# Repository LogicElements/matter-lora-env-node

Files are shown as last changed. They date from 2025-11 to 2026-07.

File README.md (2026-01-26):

# LocuSense – Low-Power CO₂ / T / RH / VOC Node (LoRaWAN / Matter over Thread)

LocuSense is a **battery-powered environmental sensing node** for CO₂, temperature, humidity and VOC index.
It is built around an ultra-low-power **STM32U0** MCU and can be equipped with **one of two mutually exclusive
communication modules**:

- **LoRaWAN (Wio-E5)** – long-range, ultra-low-power operation (few µA sleep current)
- **ESP32-C6 (Matter over Thread)** – fully integrated with Home Assistant as a sleepy end device (SED)

A 2.13" e-ink display shows current air quality and device status. It can be safely omitted in
long-life, headless deployments where every µA matters.

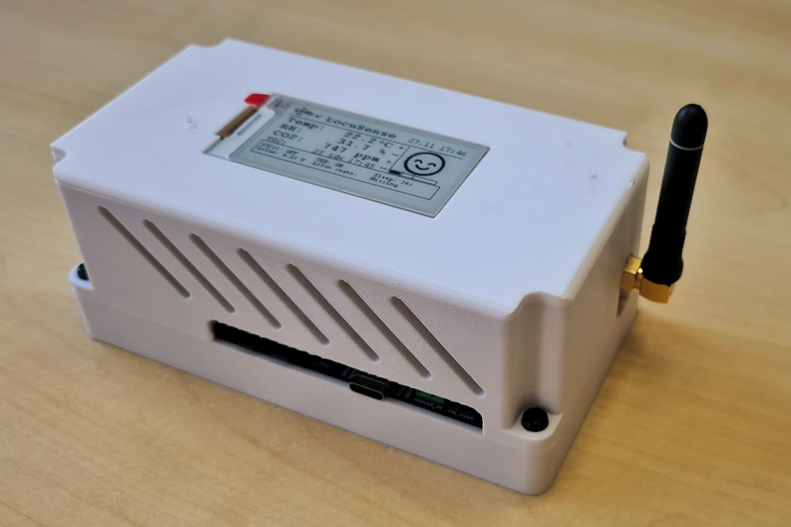
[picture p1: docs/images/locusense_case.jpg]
LocuSense node with e-ink display

---

## Features

### Sensing

- **CO₂** – Sensirion **SCD41**
- **Temperature & humidity** – Sensirion **SHT41**
- **VOC index** – Sensirion **SGP40** with official Gas Index Algorithm (VOC index)

### Power & batteries

- **STM32U0** ultra-low-power MCU
- Designed for **very low standby current** (few µA in LoRa STOP2 mode):
  - Switchable sensor / RF / e-ink power rails
  - Switchable pull-ups and resistor dividers
  - Deep sleep of external radios (Wio-E5 sleep, ESP32-C6 SED + light sleep)
- Dual battery support:
  - **LiSOCl₂ primary cell** for **multi-year, maintenance-free deployments**
  - **Li-Ion** secondary cell with **USB-C charging** via **BQ25185**
- Both batteries are measured via ADC and reported to the GUI and (for ESP32-C6) via
  **Matter Power Source cluster** (USB + Li-Ion + LiSOCl₂ endpoints).

> **Note:** The design does **not enforce a single “primary” source**. Which battery you use depends
> on your application profile (see [Typical use cases](#typical-use-cases)).

### Communication (choose one module per board)

- **LoRaWAN module – Seeed Wio-E5**
  - Configurable OTAA keys (AppEUI, DevEUI, AppKey, ADR flag)
  - Integration with **The Things Network (TTN)**
  - 6-byte payload: **T(0.01°C), RH(0.01%), CO₂ ppm**
  - Example **MQTT → Node-RED → Home Assistant** flow provided
- **ESP32-C6 module – Matter over Thread**
  - Thread sleepy end device (SED)
  - Exposes:
    - **TemperatureMeasurement cluster**
    - **RelativeHumidityMeasurement cluster**
    - **AirQuality cluster** (mapped from CO₂)
    - **Custom CO₂ concentration cluster** (0x040D, MEA feature)
    - **Power Source cluster** for USB, Li-Ion, LiSOCl₂
  - Text-based UART protocol between STM32 and ESP32-C6 (DATA / STATUS / COMM / QR …)

Only one of these modules is populated and connected to the RF connector; firmware detects the
configured communication mode and drives either **LoRaWAN** or **Matter** with no code changes
on your side.

### Local UI – e-ink display

- 2.13" e-ink (Waveshare / Good Display, `EPD_2in13_V4`)
- Shows:
  - CO₂ (ppm) + compact gauge with thresholds
  - Temperature and RH with tiny trend arrows
  - VOC index (when USB + VOC mode are enabled)
  - Connection state (LoRa or Matter)
  - Battery voltages (LiSOCl₂, Li-Ion), USB and charger status
  - Current sleep interval
- Uses **change-based refresh policy**:
  - Full redraw only when a **significant change** occurs
  - Small partial refreshes for state line and VOC updates
  - This minimizes e-ink wear and **saves power**, not just network traffic

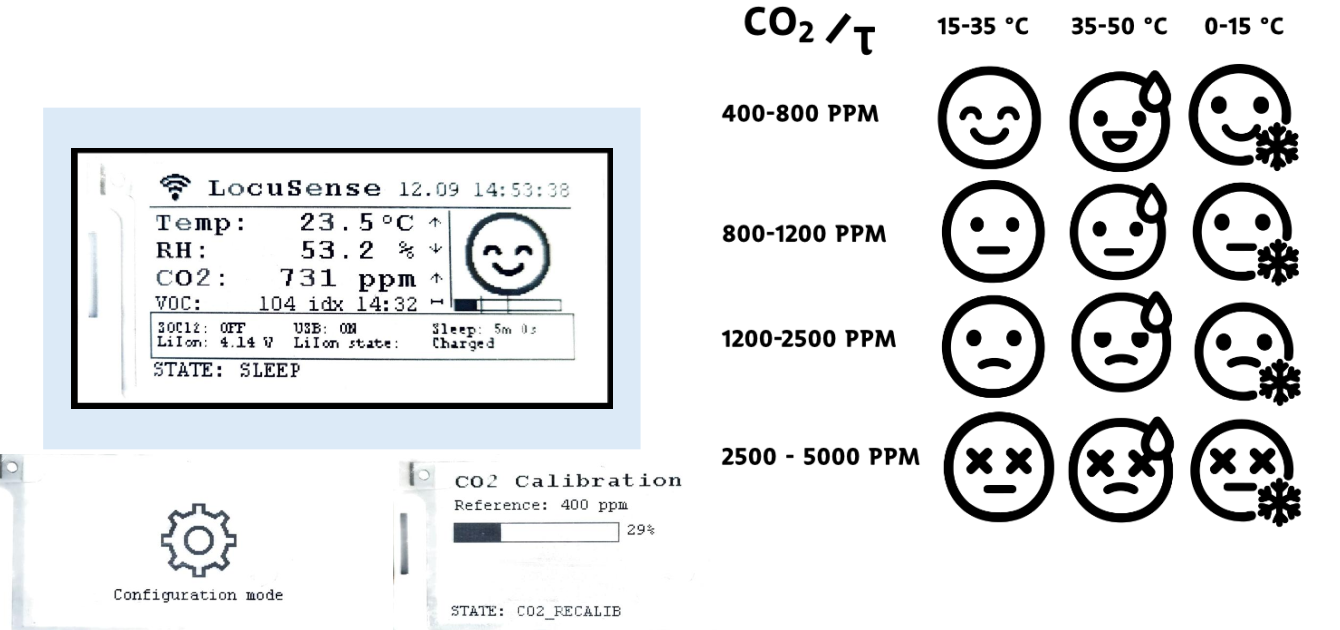
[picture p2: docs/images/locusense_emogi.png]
LocuSense e-ink display


### Home Assistant integration

- **Home Assistant Green + Home Assistant Connect ZBT-1/ZBT-2 configured for Thread** (used in development)
  - LocuSense appears as a Matter device with multiple sensors and power sources
  - Ready-to-use HA dashboard configuration included
- Data flow options:
  - **Matter over Thread (ESP32-C6)** – native Matter device
  - **LoRaWAN via TTN → (MQTT → Node-RED → Home Assistant)** - in my example
- For detailed Home Assistant walkthroughs see:
  - [Matter over Thread integration guide](home-assistant/matter/README.md) – commissioning, dashboard YAML, InfluxDB / Grafana embedding.
  - [LoRaWAN → MQTT → Node-RED → Home Assistant guide](home-assistant/lora/README.md) – TTN setup, payload decoding, Node-RED flows and dashboards.

### Data storage & analytics

- Example stack:
  - **InfluxDB** for time-series storage
- **Grafana** dashboards for CO₂ / T / RH / VOC trends
- Sample dashboard JSON is provided.

## Documentation map

Use these focused guides for deeper dives:

- [Firmware – STM32U0 (LoRaWAN + orchestration)](firmware/stm32/README.md): state machine, configuration console and EEPROM layout.
- [Firmware – ESP32-C6 bridge (Matter over Thread)](firmware/esp32c6/README.md): ESP-Matter Sleepy End Device, UART protocol and commissioning helpers.
- [Home Assistant – Matter over Thread integration](home-assistant/matter/README.md): Thread network prep, commissioning, dashboards and Grafana embedding.
- [Home Assistant – LoRaWAN → TTN → MQTT → Node-RED pipeline](home-assistant/lora/README.md): OTAA provisioning, payload decoder, Node-RED flow and HA dashboards.

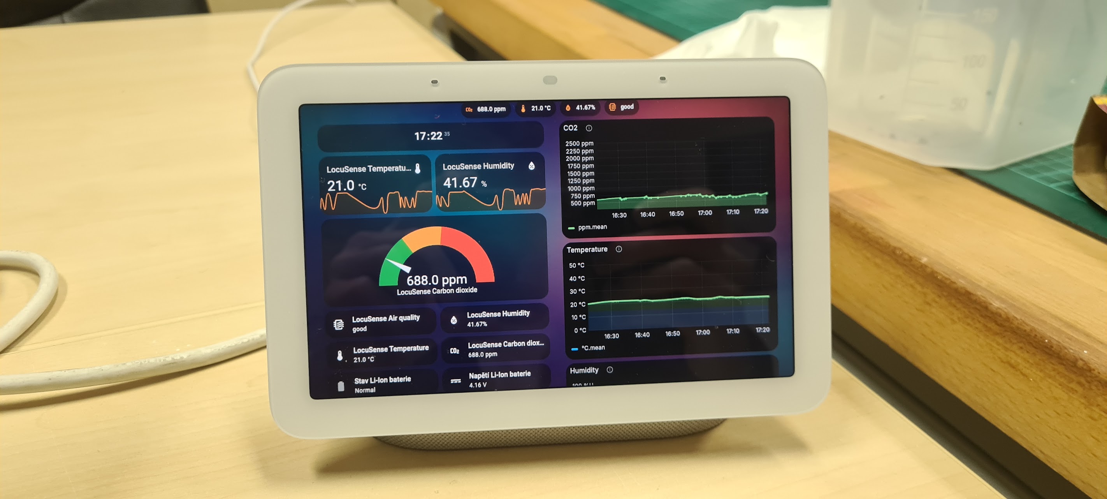
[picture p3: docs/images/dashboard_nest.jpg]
Grafana dashboard example


---

## Typical use cases

LocuSense is intentionally designed for two main scenarios:

### 1. Long-term building monitoring (LoRaWAN + LiSOCl₂)

- Application: schools, offices, public buildings, multi-room deployments
- Recommended configuration:
  - **Battery:** LiSOCl₂ primary cell
  - **Radio:** Wio-E5 (LoRaWAN → TTN → MQTT → ...)
  - **Display:** e-ink optionally **not populated** (headless sensors in classrooms, corridors)
  - **VOC:** disabled to minimize current consumption
- Example timing:
  - `measure_mode = CO₂+T+RH`
  - `interval_measure_sec = 3600` (measure **once per hour**)
  - `interval_sleep_sec   = 3600` (sleep until next cycle)
  - `tx_min_interval_sec  = 3600` (one update per measurement)
  - `tx_max_interval_sec  = 21600` (heartbeat every 6 h)

These settings are tuned for **multi-year battery life** on LiSOCl₂ while still providing useful
CO₂ and comfort trends.

### 2. Personal air-quality monitor (Matter + Li-Ion + e-ink)

- Application: desks, home office, bedrooms, meeting rooms
- Recommended configuration:
  - **Battery:** Li-Ion (rechargeable) + occasional USB-C top-up
  - **Radio:** ESP32-C6, Matter over Thread, paired to Home Assistant
  - **Display:** e-ink populated, always showing the current status
  - **VOC:** continuous VOC index when USB is present
- Example timing:
  - `measure_mode = CO₂+T+RH`
  - `interval_measure_sec = 900` (measure every **15 minutes**)
  - `interval_sleep_sec   = 900`
  - `tx_min_interval_sec  = 900` (one update per measurement)
  - `tx_max_interval_sec  = 3600` (heartbeat every hour)

Even in this “personal gadget” mode the device still aims to be **low-power**. It does **not**
need to be permanently powered via USB—USB is mainly for charging and optional continuous VOC
sampling.

---

## Getting started

1. Decide which RF module you will populate (Wio-E5 for LoRaWAN, ESP32-C6 for Matter).
2. Provision the matching firmware and configuration:
   - LoRaWAN: flash the STM32 image, set OTAA keys via the UART console, and pair with TTN.
   - Matter: flash the STM32 image plus the ESP32-C6 image, then commission the Matter device
     using the QR/manual codes.
3. Adjust measurement and transmission intervals in CONFIG mode to fit your deployment (see the
   [typical use cases](#typical-use-cases)).
4. Confirm data flow in your backend (MQTT/Node-RED/Home Assistant or Matter controller) before
   sealing the enclosure.

---

## Repository structure

Current top-level layout:

```text
.
├── .vscode/                   # Editor tasks/snippets
├── docs/
│   └── images/                # Photos and screenshots used in the README
├── firmware/
│   ├── esp32c6/               # ESP-Matter (Thread) bridge
│   └── stm32/                 # STM32U0 application, GUI, and drivers
├── hardware/                  # Altium Designer sources, and PCB outputs
├── home-assistant/            # HA dashboards, TTN/Node-RED helpers, Matter guide
└── README.md
```

Each firmware directory also ships with its own README that dives into the UART protocol,
state machine, and build/flash steps.

---

## Configuration & EEPROM (M24C02)

Each **communication module** (LoRaWAN Wio-E5 carrier or ESP32-C6 carrier) includes its own
**M24C02 I²C EEPROM**. That EEPROM holds everything the node needs to know about:

- which communication stack to use, and
- how it should behave in the field.

Stored data:

- **Device config (`AppConfig`)**
  - Measurement mode (CO₂+T+RH vs T+RH only)
  - VOC mode (disabled vs continuous on USB)
  - Communication mode (OFFLINE / LoRa / Matter)
  - Measurement / sleep / time-sync / battery intervals
  - TX thresholds for CO₂, T, RH
- **LoRaWAN (Wio-E5) OTAA credentials**
  - AppEUI, DevEUI, AppKey, ADR flag
- **ESP32-C6 pairing data**
  - Last Matter QR string
  - Manual pairing code

On every **cold boot**, the STM32:

1. Powers the sensor and RF rails.
2. Enables I²C pull-ups.
3. Probes the attached communication module and reads its **M24C02** over I²C.
4. Loads `AppConfig`, LoRa keys or ESP pairing data from that EEPROM.
5. Initializes **either** Wio-E5 **or** ESP32-C6 depending on the stored `comms_mode`.

This means you can **pre-provision communication modules** (configure once via the console
and `SAVE`), and then plug them into any LocuSense base board. The module carries its own
configuration with it; on boot, the STM32 simply reads the M24C02 and starts communication
and housekeeping according to those parameters.

---

## UART configuration console (USART4 over USB‑to‑UART)

A minimal interactive configuration console is available on **USART4**, which is routed
through the on-board **USB‑to‑UART bridge** to the USB‑C connector. In practice you just
plug the node into a PC and open a serial terminal (e.g. **Tera Term**, PuTTY, minicom)
with the parameters below while the device is in **CONFIG mode**.

- **Baud:** `115200`
- **Data bits:** 8
- **Parity:** none
- **Stop bits:** 1
- **Recommended TX delay:** **≥ 5 ms/char** in your terminal to avoid overrunning the parser.
- Console starts when you **hold the button for ≥ 5 s** (see [Button functions](#button-functions)).

Basic commands (non-exhaustive):

- `HELP` – print help and command summary
- `SHOW` – print current device config, Wio-E5 keys and ESP32-C6 status/QR/manual
- `SET <key> <value>` – change device-level config (measurement intervals, thresholds, modes…)
- `RESET` – restore firmware defaults for `AppConfig` in RAM
- `SAVE` – store current `AppConfig`, Wio OTAA keys and ESP pairing data to EEPROM (M24C02) on the module
- `EXIT` – leave CONFIG mode (same as a second ≥5 s button hold or inactivity timeout)

Supported `SET <key> <value>` options (mirrors `Core/Src/conf_console.c`):

| Key (alias) | Allowed values / units | Purpose |
|---|---|---|
| `measure_mode` (`mm`) | `0` = CO2+T+RH, `1` = T+RH only | Pick which sensors run each cycle. |
| `voc_mode` (`voc`) | `0` = disabled, `1` = VOC only when USB power is present | Gate VOC sampling to save power on battery. |
| `comms_mode` (`comms`) | `0` = offline GUI, `1` = LoRaWAN (Wio-E5), `2` = Matter over Thread (ESP32-C6 build) | Select the radio backend that the STM32 should drive. |
| `interval_measure_sec` (`tm`)| Seconds | Measurement cadence (CO2/T/RH or T/RH). |
| `interval_sleep_sec` (`ts`) | Seconds | STOP2 sleep duration between measurement cycles (when VOC is idle). |
| `interval_time_req_sec` (`tt`)| Seconds (`0` disables) | LoRaWAN network time-sync interval. |
| `interval_bat_sec` (`tb`) | Seconds | Battery/USB/charger measurement cadence. |
| `tx_min_interval_sec` (`txmin`)| Seconds | Minimum spacing between radio uplinks. |
| `tx_max_interval_sec` (`txmax`)| Seconds (`0` disables heartbeat) | Maximum silence before forcing a heartbeat uplink. |
| `th_temp_01C` (`dT`) | Delta in 0.01 °C (e.g. `20` = 0.20 °C) | Temperature change threshold that triggers TX/GUI updates. |
| `th_rh_01pct` (`dRH`) | Delta in 0.01 %RH (e.g. `100` = 1.00 %RH) | Humidity change threshold. |
| `th_co2_ppm` (`dCO2`) | Delta in ppm (e.g. `50`) | CO2 change threshold. |

> Enter the numeric value when using `SET`, e.g. `SET comms_mode 2` selects Matter over Thread and `SET comms_mode 1` selects LoRaWAN.

### LoRaWAN-related console commands

- `WIO SHOW` – show current AppEUI / DevEUI / AppKey / ADR
- `WIO SET APP_EUI <16hex>`
- `WIO SET DEV_EUI <16hex>`
- `WIO SET APP_KEY <32hex>`
- `WIO SET ADR <0|1>`
- `WIO JOIN` – perform an immediate OTAA join
- `WIO SEND HEX <12hex>` / `WIO SENDU HEX <12hex>` – confirmed / unconfirmed uplink
- `WIO SEND KV T=<i16> RH=<u16> CO2=<u16>` – build a 6-byte payload from values and send
- `WIO TIME` – request current UNIX time over LoRaWAN. A TTN + Node‑RED flow decodes the
  uplink and returns a 4‑byte timestamp which is then written into the STM32 RTC.

### ESP32-C6 / Matter-related console commands

- `ESP PING` – check the UART link to ESP32-C6
- `ESP STATUS` – query current status (`STATUS ONLINE role=SED` or `STATUS OFFLINE`)
- `ESP VERSION` – print firmware/version info
- `ESP QR` – request Matter QR & manual pairing codes
  - Text is printed on UART **and** a QR code is drawn on the e-ink display.
- `ESP COMM START` – open a Matter commissioning window
  - Device responds with `COMM STATE ...` and QR data; QR is also rendered on e-ink.
- `ESP COMM STOP` – close the commissioning window
- `ESP FABRICS` – list stored fabrics/controllers
- `ESP FACTORYRESET` – factory-reset the ESP32-C6 (clears fabrics/commissioning info)
- `ESP SEND HEX <12hex>` / `ESP SEND KV ...` – send a 6-byte payload via Matter text frame

The ESP32-C6 firmware also emits progress/status messages back over UART (`COMM STATE ...`,
`COMM DONE`, `COMM TIMEOUT`, etc.), which you can see in your terminal when commissioning
the device.

---

## Transmission & e-ink update policy (power-oriented)

To **save energy** (and not only to avoid spamming the network), both radio transmissions
and e-ink updates are **event-driven**:

### Radio TX (LoRa / Matter)

A new payload is sent only when all of these conditions are satisfied:

- Communication mode is `COMMS_LORA` or `COMMS_MATTER` (not OFFLINE)
- A baseline payload exists (first measured packet always sets it)
- **Minimum TX interval** has elapsed since the last uplink
- **At least one threshold** is exceeded compared to the last sent payload:
  - |ΔT| ≥ `th_temp_01C` (0.01 °C units)
  - |ΔRH| ≥ `th_rh_01pct` (0.01 %RH units)
  - |ΔCO₂| ≥ `th_co2_ppm` (ppm)
- Or the **heartbeat** interval `tx_max_interval_sec` has elapsed (periodic refresh)

You can tune these thresholds in CONFIG mode using `SET` commands, for example:

```text
SET dT 20       # 0.20 °C
SET dRH 100     # 1.00 %RH
SET dCO2 50     # 50 ppm
```

### E-ink redraw

The e-ink is **not** refreshed on every wake-up. A full GUI redraw happens when:

- The panel was blank (first boot)
- Communication state changes (connected / disconnected)
- USB plug/unplug, charger status, battery presence or voltage change (above hysteresis)
- Main measurable values change beyond TX thresholds or cross “emoji buckets”
  (CO₂ bands 800 / 1200 / 2500 ppm, temperature bands 15 / 35 °C)

Between full redraws, only tiny partial regions are updated:

- State line at the bottom (current FSM state)
- VOC line when new VOC index samples are available

This significantly reduces e-ink wear and display power consumption.

---

## Button functions

The front button is multi-function and time-based:

- **Short press**  
  Wake the node from STOP2 sleep (LoRa mode) and force a measurement/UI refresh.

- **Hold ≥ 5 s — enter/exit CONFIG mode**  
  - Enters the UART configuration console on `USART4` at **115200 8N1**.  
  - You can also leave CONFIG mode with the `EXIT` command or by another ≥ 5 s hold.  
  - For reliable input, set your terminal transmit delay to **≥ 5 ms/char**.

- **Hold 15–29 s — force SCD41 recalibration to 400 ppm**  
  - 400 ppm is the **typical CO₂ concentration in fresh outdoor air**.  
  - Recommended procedure:
    1. Take the device to **clean outdoor air** (away from people, traffic, exhausts).
    2. Let it **stabilize for at least 15 minutes** in that environment.
    3. Then press and hold the button for **15–29 s** to trigger the recalibration.
  - For most installations, doing this **about once per year** is sufficient,
    or whenever you suspect the CO₂ reading has drifted.

- **Hold ≥ 30 s — full system reset**  
  - Triggers a system reset of the STM32.  
  - Configuration stored in the M24C02 EEPROM (measurement config, LoRa keys, ESP pairing)
    is **preserved** unless explicitly cleared in firmware.

---

## LoRaWAN → TTN → Home Assistant example

For LoRa deployments, the node talks to a **Wio-E5** module using a simple AT-style driver.

- OTAA join is handled automatically on boot and on recover.
- Example integration flow:
  1. Wio-E5 joins **The Things Network (TTN)**.
  2. TTN pushes uplinks to **MQTT**.
  3. A **Node-RED** flow (provided) decodes the 6-byte payload into CO₂ / T / RH values.
  4. Node-RED publishes these as **Home Assistant MQTT sensors** (via discovery or HA add-on).

Additionally, a small TTN + Node-RED helper flow is used for **time synchronisation**: the
node sends a dedicated uplink, Node-RED calculates the current UNIX timestamp and returns
it as a 4‑byte downlink payload. The firmware parses this frame and updates the STM32 RTC
so logged samples carry a real wall‑clock time.

An example Node-RED flow is provided in [`home-assistant/lora/lora_ttn_ha_flow.json`](home-assistant/lora/lora_ttn_ha_flow.json),
while the TTN payload decoder lives alongside the Home Assistant YAML under [`home-assistant/lora`](home-assistant/lora/).

---

## Matter over Thread – Home Assistant & Google Nest Hub

With the ESP32-C6 module populated and `comms_mode = COMMS_MATTER`, the device acts as a
**Matter over Thread sleepy end device**:

- Tested with **Home Assistant Green + Home Assistant Connect ZBT-1/ZBT-2** (configured as Thread border router).
- Exposes:
  - Temperature, humidity, air quality (from CO₂)
  - CO₂ concentration cluster (0x040D, MEA)
  - Power Source info for USB, Li-Ion and LiSOCl₂

Pairing workflow: use the quick steps below, or jump to the detailed guide.

Quick steps (Home Assistant / Google Nest Hub):

1. Enter the console by holding the button for ~5 s.
2. If the device was paired to another fabric, check `ESP FABRICS`; recommended: run `ESP FACTORYRESET` (factory-reset the ESP32-C6, clears fabrics/commissioning info).
3. Run `ESP COMM START`.
4. Finish commissioning by pairing the device via the QR code in your controller.
5. After commissioning completes, type `EXIT`.

For a step-by-step walkthrough (Thread network prep, dashboards, Grafana embedding), see
[`home-assistant/matter/README.md`](home-assistant/matter/README.md).

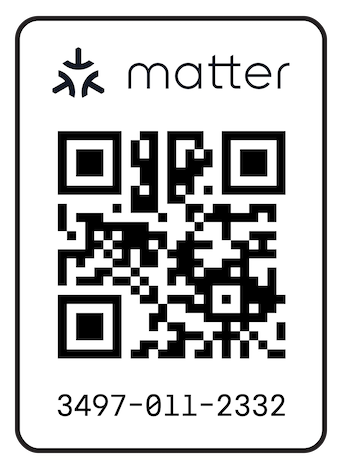
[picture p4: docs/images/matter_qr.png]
Matter pairing and e-ink QR


### Google Nest Hub

The same Matter endpoint can in principle be paired with a **Google Nest Hub**. However,
support for some clusters (especially custom CO₂ cluster and power source details) may be
limited on current Nest firmware. Standard temperature / humidity / air quality should be
usable, but cluster coverage may vary between ecosystems.

> **Note for Nest:** Google’s Matter guidance for Thread SED/SSED devices calls for **≤3 s sleep** to keep service parity; longer poll cycles can make the device appear offline in Google Home Graph. Home Assistant tolerates longer intervals, but if you target Nest favor the SIT ICD preset (fast/slow poll 0.5/5 s) instead of the LIT profile.
See the ICD preset tables and interval descriptions in `firmware/esp32c6/README.md` for how to switch between SIT/LIT in `sdkconfig`.

---

## Building & flashing

### STM32U0 firmware

- Project structured for **STM32CubeIDE** (or generic Makefile/CMake if you prefer).
- Key files:
  - `firmware/stm32/app/app.c` – main state machine (INIT → MEASURE → BAT_MEASURE → SEND_DATA → ...)
  - `firmware/stm32/app/GUI.c` – e-ink GUI
  - `firmware/stm32/app/conf_console.c` – UART config console

### ESP32-C6 firmware (Matter)

- Based on **esp-matter** and **ESP-IDF** (version as in your environment).
- Main application: `firmware/esp32c6/main/app_main.cpp`
  - Sets up Matter node and endpoints
  - Implements the **text-based UART protocol** with STM32
  - Manages WAKE/READY handshake and light sleep
- Typical build steps:

```bash
cd firmware/esp32c6
idf.py set-target esp32c6
idf.py build
idf.py flash monitor
```

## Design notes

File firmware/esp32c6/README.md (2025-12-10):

Matter Multi-Sensor (UART)
==========================

Matter over Thread application for an ESP32-C6 Sleepy End Device (SED) that acts as a bridge for an external STM32-based sensor head. The ESP32 exposes three environmental sensors (temperature, humidity, CO₂) plus three Matter Power Source endpoints while the STM32 pushes measurements over a simple ASCII UART protocol.

The design goal is reliability with minimal wake time: the ESP32 sleeps between Thread polls, wakes instantly on `WAKE`, and mirrors STM32 telemetry to Matter clusters without additional parsing on the controller side.

> **Related docs:** [Project overview](../../README.md) for hardware context, [STM32 firmware README](../stm32/README.md) for the sensor-side state machine, and [Home Assistant Matter guide](../../home-assistant/matter/README.md) for commissioning and dashboards.

Key features
------------
- ESP-Matter based Matter-over-Thread SED with commissioning helpers (QR/manual codes sent over UART).
- Low-speed UART (9600 Bd) plus WAKE/READY GPIO handshake so the STM32 can wake the ESP32 from light sleep when a frame is ready to send.
- Environmental telemetry comes from the STM32 (`DATA ...` frames) and is mapped to Matter Temperature Measurement, Relative Humidity Measurement, Air Quality, and the custom Concentration Measurement cluster (CO₂).
- Rich power-source modelling: independent endpoints for USB (wired), Li-Ion (rechargeable), and LiSOCl₂ (primary cell) including voltage, presence and charge/replace status derived from telemetry.
- UART command channel allows the STM32 to control commissioning (`COMM START/STOP`), factory reset, QR/manual code retrieval, and to query fabrics or runtime status.
- Light-sleep aware architecture: the ESP32 drops into light sleep between Thread poll intervals and only wakes when `WAKE` rises or when Matter stack work (commissioning/events) is pending.

Hardware & wiring
-----------------
- **MCU**: ESP32-C6, built as a low-power Sleepy End Device (Thread stack enabled in `sdkconfig`).
- **UART**: `UART1` @ 9600 baud, 8N1.
  - `GPIO5` – ESP TX → STM32 RX
  - `GPIO4` – ESP RX ← STM32 TX
  - Idle lines stay HIGH. CRLF (`\r\n`) terminates every line.
- **Handshake GPIOs**:
  - `WAKE` (`GPIO2`, input, RTC capable). Driven HIGH by the STM32 to signal that a frame is ready and to wake the ESP32 from light sleep.
  - `READY` (`GPIO3`, output). Raised by the ESP32 once it is ready to read a frame; the STM32 should only transmit while `READY=1`.
- **Power meta telemetry**: The STM32 reports Li-Ion, LiSOCl₂ and USB state (voltages, charger state) through `DATA BAT ...` lines. Those values are forwarded to the relevant Matter Power Source clusters.

Prerequisites
-------------
- ESP-IDF with esp-matter support (v5.2 or v5.3 are known-good).
- A serial/JTAG adapter wired to `UART1` pins and access to the WAKE/READY GPIOs.
- A Thread border router in your test environment (Home Assistant + Home Assistant Connect ZBT-1/ZBT-2 works well).

Thread SED & light-sleep behavior
---------------------------------
- The device runs as a Thread Sleepy End Device, so after finishing Matter/FreeRTOS work it quickly enters light sleep to reduce consumption.
- ESP-IDF PM configuration keeps the CPU at a fixed frequency but enables light sleep whenever the idle task runs; the OpenThread stack schedules periodic polls to keep parent links alive.
- UART activity gates sleep via the WAKE/READY handshake:
  - STM32 asserts `WAKE` to wake the ESP32 (WAKE is RTC capable, so it exits light sleep immediately).
  - The UART task raises `READY`, acquires a PM lock (`esp_pm_lock_acquire()`), drains the line, processes the incoming `DATA`/command line, and only then releases the lock and lowers `READY`.
  - As soon as `READY` falls and no further work is pending, the ESP32 returns to light sleep until the next Thread poll or WAKE event.
- Commissioning and other Matter tasks can also keep the chip awake temporarily; once those tasks finish, the default behavior is to sleep again unless the STM32 keeps the link busy.

ICD presets in `sdkconfig`
--------------------------
This SED follows the esp-matter ICD example profiles (`examples/icd_app`) so you can pick between Short Idle Time (SIT) and Long Idle Time (LIT) behavior by selecting a preset `sdkconfig.defaults.*` file before regenerating `sdkconfig`.

**Default SIT profile (current `sdkconfig.defaults`):**

| Parameter | Value |
| --- | --- |
| ICD Fast Polling Interval | 500 ms |
| ICD Slow Polling Interval | 3000 ms |
| ICD Active Mode Duration | 1000 ms |
| ICD Idle Mode Duration | 60 s |
| ICD Active Mode Threshold | 1000 ms |

**Optional LIT profile (`sdkconfig.defaults.esp32c6.lit` or `.esp32h2.lit`):**

| Parameter | Value |
| --- | --- |
| ICD Fast Polling Interval | 500 ms |
| ICD Slow Polling Interval | 20000 ms |
| ICD Active Mode Duration | 1000 ms |
| ICD Idle Mode Duration | 600 s |
| ICD Active Mode Threshold | 5000 ms |

Pick the preset that matches your responsiveness vs. power target, then run `idf.py set-target esp32c6` followed by `idf.py reconfigure` to apply the chosen defaults. SIT gives snappier reaction to new data at the cost of more parent polls; LIT stretches the idle window and slow poll interval for lower average current on battery.

> Nest compatibility: Google wants Thread SED/SSED devices to keep sleep intervals <= 3 s to avoid being shown offline. Use the SIT preset (slow poll 3000 ms) for Nest Hub; LIT’s 20 s slow poll is too long for Google’s limits but fine for Home Assistant.

What each interval does:
- Fast Polling Interval: how often the SED asks its parent for pending data while it considers itself active (short, responsive window).
- Slow Polling Interval: how often it polls in idle mode (dominant factor for average current).
- Active Mode Duration: how long the device stays in the fast-poll state after activity such as UART traffic or a Matter event.
- Idle Mode Duration: how long the device remains in idle before considering a re-entry to active mode.
- Active Mode Threshold: minimum elapsed time between fast-poll periods; shorter values bias toward responsiveness, longer values bias toward lower current.

Estimated current draw (ESP32-C6 module only, no radio TX):
- SIT preset: ~0.25-0.35 mA average in steady idle (Thread polls every 5 s, brief wake bursts).
- LIT preset: ~0.10-0.15 mA average in steady idle (20 s slow polls dominate).
- Active UART window or commissioning: 8-15 mA while the CPU stays awake; Thread TX/RX spikes add short peaks. The STM32 and sensors add on top of these numbers.

UART text protocol
------------------
Every UART frame is a single ASCII line terminated with `CRLF`. The STM32 is the master that asserts `WAKE`, waits for `READY=1`, sends one line, and then releases `WAKE`.

### DATA frames (STM32 → ESP32)

| Syntax | Purpose | Notes |
| --- | --- | --- |
| `DATA HEX <12 hex digits>` | Compact binary payload (T/RH/CO₂). | Bytes: `T_hi T_lo RH_hi RH_lo CO2_hi CO2_lo`. Temperature is 0.01 °C units, humidity 0.01 % RH, CO₂ ppm. |
| `DATA KV T=<i16> RH=<u16> CO2=<u16>` | Human-readable telemetry. | Same units as HEX. |
| `DATA BAT KV LI=<u16> LS=<u16> USB=<0|1> CHG=<0..255>` | Power metadata. | `LI/LS` are millivolts for Li-Ion and LiSOCl₂ packs, `USB` indicates VBUS presence, `CHG` mirrors the raw BQ25185 charger status. |

Valid frames update Matter attributes immediately (`update_matter_clusters()` and `update_power_source_clusters_from_meta()`). Invalid data (out-of-range numbers or malformed payloads) is ignored and only logged.

### Command frames (STM32 ↔ ESP32)

STM32 may initiate the following commands; every command receives at least one response line via `replyf()`:

| Command | Response(s) | Notes |
| --- | --- | --- |
| `PING` | `PONG` | Health check. |
| `STATUS?` | `STATUS ONLINE role=SED` or `STATUS OFFLINE` | Thread attachment status. |
| `QR?` / `GET QR` | `COMM QR <code>` + `COMM MANUAL <code>` | Forces regeneration of QR and manual setup payloads. |
| `VERSION?` | `VERSION app=1.0.0 idf=<idf version> matter=1.x` | Firmware identification. |
| `FACTORYRESET` | `OK` | Triggers `InitiateFactoryReset()` on the Matter stack thread. |
| `FABRICS?` | Multi-line dump bracketed by `FABRICS BEGIN/END`. Each entry looks like `FABRIC idx=...` with compressed ID, fabric ID, node ID and vendor ID. |
| `COMM START` / `COMMISSION OPEN` | `COMM STATE Discover` + QR/manual lines | Schedules `OpenBasicCommissioningWindow()` for 10 minutes. |
| `COMM STOP` / `COMMISSION CLOSE` | `COMM STATE Closed` + `COMM CLOSED` | Calls `CloseCommissioningWindow()`. |
| (any other string) | `ERR unknown` | Default case. |

Additional asynchronous responses:
- `COMM STATE <Discover|Connected|Timeout|Closed|Complete|Stopped>` whenever Matter emits the respective commissioning events.
- `COMM QR ...`, `COMM MANUAL ...`, `COMM DONE`, `COMM TIMEOUT`, `COMM CLOSED` for higher-level commissioning state reporting.
- `STATUS ...` lines may also be pushed proactively when Thread state changes.

### Console hooks on the STM32 side

All of the commands above are exposed to the end user through the STM32 UART console
(`firmware/stm32/Core/Src/conf_console.c`). Typical usage:

- `ESP PING` / `ESP STATUS` / `ESP VERSION` — verify UART health and cached runtime status.
- `ESP QR` together with `ESP COMM START` / `ESP COMM STOP` — pull fresh QR/manual codes and open/close the Matter commissioning window (the STM32 also caches the data in EEPROM and draws the QR on the E-Ink UI).
- `ESP FABRICS`, `ESP FABRIC REMOVE <idx>`, `ESP FACTORYRESET` — manage stored commissioners without touching ESP-IDF firmware.
- `ESP SEND HEX|KV ...` — transmit ad-hoc telemetry frames via Matter for testing.

Make sure the STM32 config console stays on `comms_mode = COMMS_MATTER`, adjust measurement/telemetry intervals as needed, then `SAVE` to persist both STM32 config and ESP pairing data to EEPROM before rebooting.

Matter endpoints & clusters
---------------------------
- **Endpoint 1 – Temperature sensor**: standard Temperature Measurement cluster with ±40 °C to 125 °C range (0.01 °C format).
- **Endpoint 2 – Humidity sensor**: Relative Humidity Measurement cluster (0–100 % in 0.01 % units).
- **Endpoint 3 – Air quality / CO₂**:
  - Air Quality cluster (0x005B) exposing only the `AirQuality` attribute. The qualitative state is derived from CO₂ ppm thresholds (`Good` < 800 ppm → `ExtremelyPoor` ≥ 3000 ppm).
  - Concentration Measurement cluster (0x040D) configured for CO₂ in ppm (MEA feature, measurement medium “Air”). Attributes include `MeasuredValue`, `Min/MaxMeasuredValue`, `MeasurementUnit`, `MeasurementMedium`, and `Uncertainty`.
- **Endpoints 4–6 – Power Source clusters** (`init_power_source_endpoints()`):
  - USB wired source: `Status`/`WiredPresent`.
  - Li-Ion rechargeable source: voltage, presence, replacement-needed, charge level and charge state mapped from STM32 telemetry + BQ25185 status codes.
  - LiSOCl₂ replaceable source: voltage, presence, replacement-needed and coarse charge level heuristics.

Building & flashing
-------------------
1. Export the ESP-IDF environment that includes esp-matter (esp-idf v5.2/v5.3 works best). Example:
   ```bash
   source ~/esp/esp-idf/export.sh
   ```
2. Select the board target (the defaults assume ESP32-C6):
   ```bash
   idf.py set-target esp32c6
   ```
   Optional preset configs are provided under `sdkconfig.defaults.*` if you need to regenerate `sdkconfig`.
3. Build, flash and start a monitor:
   ```bash
   idf.py -p /dev/ttyUSB0 build flash monitor
   ```
4. Connect the STM32 UART and WAKE/READY lines after flashing so the ESP32 can immediately begin reading frames.

During development you can use `idf.py monitor` to watch the UART handshake logs (`UART RX task started`, `WAKE HIGH`, `DATA parse failed`, etc.). The monitor also shows the generated QR/manual codes when a commissioning window opens.

Bringing the system up
----------------------
1. Power on both MCUs; ensure the STM32 keeps `WAKE=LOW` until it sees `READY=HIGH` to avoid dropping frames at boot.
2. Send a `PING` frame to verify the UART link. If you do not receive `PONG`, check wiring or baud rate.
3. Issue `COMM START` to open a commissioning window and wait for the `COMM STATE Discover` message followed by the QR/manual payload. Use those codes to onboard the device with your Matter controller.
4. Begin streaming periodic `DATA` frames (either `HEX` or `KV`). The ESP32 updates the Matter attributes immediately; you can verify this via your controller’s state table or by subscribing to the clusters.
5. Periodically send `DATA BAT ...` so the power-source endpoints remain in sync with the real hardware state.

Troubleshooting tips
--------------------
- If the ESP32 never responds, make sure `WAKE` is toggling and that the STM32 waits for `READY=1` before transmitting.
- Commissioning commands run on the Matter platform thread; keep sending `COMM START` until you see `COMM STATE Discover` if fabrics were previously present.
- Use `FABRICS?` to inspect currently commissioned controllers, and `FACTORYRESET` to wipe NVS if the device behaves unexpectedly.
- Light sleep is enabled when PM is configured and Thread is idle; any UART RX window automatically acquires a PM lock to avoid missed bytes. If your STM32 chatters, consider batching multiple values into a single line.

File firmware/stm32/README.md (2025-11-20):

# LocuSense STM32U0 Firmware

Firmware for the LocuSense air-quality node built around an STM32U073RCT6.
The code measures CO2/temperature/humidity/VOC with Sensirion sensors, renders the
data on a 2.13" e-paper display, pushes a compact 6-byte payload over LoRaWAN or
Matter/Thread (via ESP32-C6), and turns power rails on/off aggressively to maximize
runtime from the Li-Ion + LiSOCl₂ hybrid battery pack.

> **See also:** [project overview](../../README.md) for hardware context, [ESP32-C6 firmware](../esp32c6/README.md) for the Matter bridge, and the Home Assistant guides ([Matter](../../home-assistant/matter/README.md) / [LoRaWAN](../../home-assistant/lora/README.md)) for end-to-end integrations.

## Key Features
- **Single state machine** in `Core/Src/app.c` drives measurements, communications,
  GUI, sleep, user configuration, recovery paths, and sensor calibration.
- **Sensirion sensor stack**: SCD41 (CO2), SHT41 (T/RH), SGP40 (VOC with the
  `sensirion_gas_index_algorithm.c`). All drivers live in
  `Core/Src`.
- **Dual transport**: LoRaWAN via Seeed Wio-E5 (SPI2 + AT modem) or Matter/Thread
  using an ESP32-C6 UART bridge (`Core/Src/WioE5.c`, `Core/Src/esp32c6.c`). Offline
  GUI-only mode is also available.
- **E-paper GUI** for the Waveshare 2.13" v4 display (full dashboard, partial
  updates, QR codes) implemented in `Core/Src/GUI*.c` with bitmap assets in
  `ImageData*.c`.
- **Power management**: software controls for PS1 (sensors), PS2 (radio), PS4
  (display), and sleep GPIO handling (`Core/Src/gpio_sleep.c`) to reach STOP2.
- **User configuration tools**: PB11 button (5 s = CONFIG, 15 s = recalibration,
  30 s = reset) and an interactive UART4 console with HELP menu
  (`Core/Src/button_handler.c`, `Core/Src/conf_console.c`).
- **Persistent storage**: I2C EEPROM M24C02 keeps `AppConfig`, Wio-E5 OTAA
  credentials, and Matter QR/manual codes (`Core/Src/ee_config.c`).

## Hardware Blocks
### MCU and Peripherals
- **STM32U073RCT6** @ 64 MHz, 256 KB Flash, 40 KB SRAM. Pin mapping comes from
  `LocuSense_final.ioc` and `Core/Inc/main.h`.
- **UART4 (PA0/PA1)** is the console/debug port; `_write()` in `Core/Src/main.c`
  routes `printf` there.
- **UART1 (PA9/PA10)** serves the ESP32-C6 bridge and can be reused for direct AT
  control of the radio.
- **SPI1** drives the e-paper panel; **SPI2** is wired to Wio-E5.
- **I2C1** talks to all Sensirion sensors plus the EEPROM.
- **ADC1** samples both battery rails and BQ25185 STAT pins.
- **LPTIM2** provides a 10 s tick for continuous VOC sampling whenever USB power
  is present.

### Communication Blocks
- **Wio-E5 LoRaWAN**: chip select / reset / GPIO pins are listed in
  `Core/Inc/main.h`. The driver in `Core/Src/WioE5.c` handles OTAA join, time
  requests, confirmed/unconfirmed uplinks, and low-power sleep.
- **ESP32-C6 Matter/Thread bridge**: WAKE on PC6, READY on PC7, ASCII command set
  for `PING`, `STATUS`, `QR`, commissioning control, and data frames is in
  `Core/Src/esp32c6.c`. All commands are also exposed through the config console.

### Sensors and Power Tree
- **SCD41, SHT41, SGP40** share the PS1 rail plus I2C pull-ups
  (PULL_CNTR). CO2 recalibration is performed inside `STATE_RECALIBRATION`.
- **BQ25185** charger monitors USB presence (`USB_ON` pin) and charger status.
  See `Core/Src/BQ25185.c` for helper functions used by GUI and telemetry.
- **External EEPROM M24C02** stores `AppConfig_t`, `WioOtaaConfig_t`, and
  `EspC6Pairing_t`.
- **GPIO essentials**: LED (PB10), user button (PB11, EXTI4_15), PSx power-switch
  pins defined in `main.h`.

## Repository Layout
- `Core/Inc`, `Core/Src` - application code, drivers, state machine, GUI.
- `Drivers` - STM32U0 HAL delivered by Cube (do not edit manually).
- `Debug`, `Release` - STM32CubeIDE build outputs (regenerate locally).
- `.mxproject`, `.ioc`, `.project`, `.cproject` - STM32CubeIDE / CubeMX metadata.
- `.vscode` - optional editor helpers.

Large bitmap sources (`ImageData*.c`, `images.c`) are generated assets; avoid
editing them manually.

## Application State Machine
`App_Run()` (`Core/Src/app.c`) iterates a `switch(app.currentState)` state machine:
1. **STATE_INIT** - handles cold boot or STOP2 wake-up, loads EEPROM config,
   initializes sensors, GUI, radios, and bookkeeping.
2. **STATE_MEASURE** - gathers CO2/T/RH (per `measureMode`), optional VOC, builds
   the 6-byte payload, and updates the GUI cache.
3. **STATE_BAT_MEASURE** - samples batteries/USB/charger according to
   `interval_bat_sec`.
4. **STATE_SEND_DATA** - checks `ShouldTxNow()` and sends via LoRa or ESP while
   tracking ACK statistics.
5. **STATE_RECOVER** - rejoins LoRa or resets ESP32-C6 after repeated failures.
6. **STATE_TIME_REQ** - triggers a LoRaWAN time downlink to sync the RTC.
7. **STATE_GUI** - performs full or partial display refreshes (`GUI.c`).
8. **STATE_SLEEP** - enters STOP2 (unless USB+VOC is active or the button is held)
   using an RTC wake-up timer.
9. **STATE_RECALIBRATION** - long button press starts SCD41 400 ppm recal and UI
   feedback.
10. **STATE_CONFIG** - halts sensors, powers ESP for QR commands, shows the config
    icon, and runs the UART4 console until exit/inactivity.

`ButtonHandler` (`Core/Src/button_handler.c`) maps press duration:
- `<5 s` - reserved for future quick actions.
- `5..14 s` - toggles the CONFIG state (`app.confFlag++`).
- `15..29 s` - requests CO2 recalibration (`app.recalibFlag = 1`).
- `>=30 s` - triggers a system reset (`NVIC_SystemReset()`).

## Configuration Console
- **How to enter:** hold PB11 for ~5 s or call `ConfConsole_Start()` directly.
- **Connection:** UART4 @ 115200 8N1 (`DBG_TX`=PA0, `DBG_RX`=PA1). In CONFIG mode
  the ESP rail stays powered (WAKE held low) so QR/STATUS commands work.
- **Commands:** `HELP` prints the full list. Highlights:
  - `SHOW`, `SET <key> <value>` manipulate `AppConfig`.
  - `WIO ...` family for OTAA keys, JOIN, confirmed/unconfirmed SEND, TIME.
  - `ESP ...` for PING/STATUS/VERSION/QR/COMM START-STOP/FABRICS/factory reset,
    plus data test frames.
  - `JOIN` (LoRa), `RESET` (restore defaults in RAM), `SAVE` (write EEPROM),
    `EXIT`.
- Each command prints textual feedback, and optional E-Ink partial updates use
  `GUI_DrawConfIcon`, `GUI_DrawConfOk`, and `GUI_DrawConfError`.

Supported `SET <key> <value>` pairs (same parser as `Core/Src/conf_console.c`):

| Key (alias) | Allowed values / units | Notes |
|---|---|---|
| `measure_mode` (`mm`) | `0` = CO2+T+RH, `1` = T+RH only | Enables/disables SCD41 sampling. |
| `voc_mode` (`voc`) | `0` = disabled, `1` = VOC only while USB is present | Continuous VOC draws more current; keep it off for pure battery. |
| `comms_mode` (`comms`) | `0` = offline GUI, `1` = LoRaWAN (Wio-E5), `2` = Matter over Thread (ESP32-C6 build) | Chooses which radio stack initializes in `STATE_INIT`. |
| `interval_measure_sec` (`tm`)| Seconds | Primary measurement cadence. |
| `interval_sleep_sec` (`ts`) | Seconds | STOP2 sleep gap between cycles when VOC is idle. |
| `interval_time_req_sec` (`tt`)| Seconds (`0` disables) | LoRa network time-sync request interval. |
| `interval_bat_sec` (`tb`) | Seconds | Battery/USB/charger measurement cadence. |
| `tx_min_interval_sec` (`txmin`)| Seconds | Minimum spacing enforced between any TX events. |
| `tx_max_interval_sec` (`txmax`)| Seconds (`0` disables heartbeat) | Forces a heartbeat if no delta-triggered TX happens before this timeout. |
| `th_temp_01C` (`dT`) | Delta in 0.01 °C | GUI/radio updates trigger once |ΔT| exceeds this. |
| `th_rh_01pct` (`dRH`) | Delta in 0.01 %RH | Same principle for humidity. |
| `th_co2_ppm` (`dCO2`) | Delta in ppm | Same principle for CO₂. |

> Always provide the numeric value in the console (e.g. `SET comms_mode 2` for Matter, `SET comms_mode 1` for LoRa).

## Communications and Payload Format
- **Payload layout**: 6 bytes total  
  `T` = int16 in 0.01 degC, `RH` = uint16 in 0.01 %RH, `CO2` = uint16 ppm.
  `build_payload_from_kv()` in `conf_console.c` mirrors the application format.
- **LoRaWAN**: `ShouldTxNow()` enforces minimum/maximum intervals (`tx_min/max`),
  delta thresholds (`th_temp_01C`, etc.), and heartbeats. `Wio_SendData()` (or
  `_SendData_Unconfirmed`) handles uplinks; ACK counters influence `STATE_RECOVER`.
- **Matter/Thread**: ESP32-C6 accepts `DATA HEX` or `DATA KV` ASCII frames with a
  WAKE/READY handshake. `EspC6_DataBat()` reports dual-battery status over Matter.
- **Offline mode**: set `app.cfg.commsMode = COMMS_OFFLINE` to keep UI/logging only.

## GUI Notes
- All rendering lives in `Core/Src/GUI.c`, `GUI_Paint.c`, and `Fonts/`.
- `GUI_Display()` draws the full dashboard (connectivity/time, CO2/T/RH/VOC grid,
  emoticon, battery strip, sleep state). `GUI_UpdateState()` and
  `GUI_UpdateVocLine()` perform partial refreshes to reduce ghosting.
- QR codes (used for Matter COMM pairing) are generated via `qrcodegen.c` and
  `GUI_DrawQr`.
- Before STOP2 the display is put to sleep via `EPD_PowerOff()`. After resume
  call `GUI_OnEPDResumed()` to rebuild the partial base image.

## Build and Flash
1. Install **STM32CubeIDE 1.15+** (or CubeMX 6.11+) with the STM32CubeU0 package.
2. `File -> Import -> Existing Projects into Workspace`, pick `firmware/stm32`.
3. When regenerating from `.ioc`, use CubeMX inside CubeIDE and keep USER CODE
   sections intact (`app.c`, `main.c`, etc.).
4. Select the `Debug` or `Release` configuration and run **Build**; binaries end
   up in the respective folders.
5. Flash via ST-LINK (`Run -> Debug`) or CLI  
   `STM32_Programmer_CLI -c port=SWD -d Debug/LocuSense_final.elf`.

> LoRaWAN/Matter features require valid OTAA credentials (set with the console)
> and a programmed ESP32-C6 firmware. Without them, `STATE_RECOVER` will keep
> trying to reconnect.

## EEPROM Defaults and Calibration
- `AppConfig_SetDefaults()` (in `app.c`) configures:
  - CO2+T+RH every 30 s (`interval_measure_sec`) with 30 s STOP2 gaps,
    LoRa heartbeat every 3600 s, delta thresholds of 0.2 degC / 1 %RH / 10 ppm.
  - `commsMode = COMMS_MATTER`, `vocMode = VOC_CONT_USB`.
- `EE_Config_Load()` / `EE_Config_Save()` use a simple magic+CRC layout that
  stores `AppConfig`, Wio OTAA keys, and ESP QR/manual strings. Invalid pages
  fall back to defaults.
- `State_Recalib()` executes `SCD41_ForceRecalibration(&hi2c1, 400)`. Make sure
  the device sits in a 400 ppm environment before triggering it.

## Development Tips
- **Adding sensors**: extend `STATE_MEASURE`, update `GUI.c`, and consider payload
  compatibility for both LoRa and Matter paths.
- **New console commands**: extend the dispatch table in `conf_console.c`.
- **Power tuning**: keep `KEEP_PINS` in `app.c` up to date so new peripherals
  survive STOP2 without leakage.
- **Testing**: stream logs over UART4 (`printf`) and watch the LED/E-Ink states.
  For LoRa debugging you can enable extra AT logs on Wio-E5 if needed.

Contributions are welcome. The most critical pieces are the application state
machine (`Core/Src/app.c`), configuration console (`Core/Src/conf_console.c`),
and GUI (`Core/Src/GUI.c`). Whenever CubeMX regeneration is required, double-check
USER CODE markers and commit the updated `.ioc`.

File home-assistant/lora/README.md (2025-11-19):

# Home Assistant LoRaWAN Example (TTN → MQTT → Node-RED → Home Assistant)

This example shows how to integrate the **LoRaWAN mode** of the LocuSense node
with **Home Assistant**, using:

- LoRaWAN end device (LocuSense node with Wio-E5)
- LoRaWAN gateway
- **The Things Network (TTN)** as LoRaWAN network server
- **MQTT** as transport from TTN to your Home Assistant
- **Node-RED add-on** inside Home Assistant to:
  - parse TTN JSON messages
  - create Home Assistant sensors via `node-red-contrib-home-assistant-websocket`

Data path is:

```text
Node → LoRa → Gateway → TTN → MQTT → Node-RED → Home Assistant
```

> ⚠️ This README only covers the **LoRaWAN path**. Matter/Thread and the ESP32‑C6
> firmware are documented separately in the Matter README.

> Firmware context: [`firmware/stm32/README.md`](../../firmware/stm32/README.md) describes the STM32 state machine,
> while [`firmware/esp32c6/README.md`](../../firmware/esp32c6/README.md) covers the ESP32-C6 bridge. For a hardware overview see the
> [project root README](../../README.md).

If you decide to run the **Matter over Thread** workflow instead, jump to the [Home Assistant Matter guide](../matter/README.md) which covers ESP32-C6 commissioning, Thread network setup and dashboard examples that complement the LoRaWAN flow described here.

### Repository assets in this folder

- `lora_ttn_ha_flow.json` – Node-RED flow imported in section 6.
- Screenshots referenced here live under `../../docs/images/` (shared with the Matter guide).

---

## 1. Requirements

- A running **Home Assistant** instance
- **Node-RED add-on** installed in Home Assistant
- TTN account + application + at least one registered device (your LocuSense node)
- LoRaWAN gateway connected to TTN
- Basic familiarity with:
  - TTN Console
  - MQTT
  - Node-RED
  - Home Assistant entities / dashboards

On the LoRaWAN side this example has been tested with:

- **Frequency plan**: `Europe 863-870 MHz (SF9 for RX2 - recommended)`
- **LoRaWAN version**: `LoRaWAN 1.0.1`
- **Regional Parameters version**: `TS001 1.0.1`

### Firmware / console checklist

- Flash the **STM32 LoRaWAN build** and in the console run
  `SET comms_mode 1` (alias `SET comms 1`) to select `COMMS_LORA`.
- Run `SHOW` (or `GET`) in the console to double-check that `comms_mode = COMMS_LORA`
  and that Matter-specific toggles stay disabled.
- Optional sanity check: `WIO SHOW` echoes the current App/Dev EUIs and confirms the module
  responds before you move on to TTN provisioning.

---

## 2. Configure the LocuSense node (OTAA)

The LocuSense node uses **OTAA** (Over-The-Air Activation). You need three
values from TTN:

- `AppEUI` (a.k.a. `JoinEUI`) – 16 hex characters
- `DevEUI` – 16 hex characters
- `AppKey` – 32 hex characters

> Make sure the firmware is in **`COMMS_LORA`** mode (`SET comms_mode 1`
> in the STM32 console) so that the LoRaWAN stack is active before you proceed.
> A full console command reference lives in `firmware/stm32/README.md`
> (see the *Configuration Console* section).

These are **stored in the LoRa communication module EEPROM** and configured
via the node's configuration console.

1. Connect the node over USB (USB–UART) to your PC.
2. Open a serial terminal (e.g. TeraTerm) at:
   - **Baud rate**: `115200`
   - **Data bits**: `8`
   - **Parity**: `None`
   - **Stop bits**: `1`
3. Enter **CONFIG mode** by holding the button for ~5 seconds at boot, then
   use commands like:

   ```text
   WIO SET APP_EUI <16-hex>
   WIO SET DEV_EUI <16-hex>
   WIO SET APP_KEY <32-hex>
   ```

4. Save configuration:

   ```text
   SAVE
   ```

A quick `WIO SHOW` printout should now show the newly stored OTAA keys. If you want to test connectivity before deploying, you can issue a manual `WIO JOIN` and watch the join status both in the console and in the TTN Application event log.

On next boot the node reads configuration from the EEPROM on the LoRa module,
joins the network via OTAA and begins periodic uplinks according to the
firmware configuration (measurement interval, thresholds, etc.).

---

## 3. TTN application & device

1. In **TTN Console**, create an **Application** or use an existing one.
2. Add a new device (end device) for your node:
   - LoRaWAN version: **1.0.1**
   - Regional params: **TS001 v1.0.1**
   - Frequency plan: **Europe 863‑870 MHz (SF9 for RX2 – recommended)**
3. Use the **OTAA** credentials (AppEUI, DevEUI, AppKey) you plan to flash
   into the node (see previous section).
4. After provisioning, you should be able to see **join requests / joins**
   and **uplink messages** in the TTN Console once the node starts sending.

---

## 4. Uplink payload formatter (temperature, humidity, CO₂)

The firmware sends a compact binary payload on **FPort 8**:

- Bytes 0–1: temperature × 100 (signed or unsigned, depending on FW)
- Bytes 2–3: humidity × 100
- Bytes 4–5: CO₂ in ppm

In the TTN Application **Payload formatters → Uplink**, select
**“Javascript”** and use:

```js
function Decoder(bytes, f_port) {
  var decoded = {};

  if (f_port === 8) {

    var temp_data = (bytes[0] << 8) | bytes[1];
    decoded.temperature = temp_data / 100;

    var hum_data = (bytes[2] << 8) | bytes[3];
    decoded.humidity = hum_data / 100;

    var co2_data = (bytes[4] << 8) | bytes[5];
    decoded.co2 = co2_data;

    return decoded;
  }

  return {};
}
```

In the **Live data** tab you should now see `decoded_payload.temperature`,
`decoded_payload.humidity` and `decoded_payload.co2` for each uplink.

---

## 5. MQTT access from Home Assistant / Node-RED

Home Assistant (Node-RED add-on) acts as an **MQTT client** and connects to
the **TTN MQTT broker**. TTN then pushes uplinks over this connection.

### 5.1 Create MQTT credentials in TTN

1. In TTN Console go to your **Application → Integrations → MQTT**.
2. Create / view your **MQTT connection details**:
   - **Server**: `eu1.cloud.thethings.network` (for EU1 region)
   - **Port**: `1883`
   - **Username**: something like `YOUR_APP_ID@ttn`
   - **Password**: a TTN **API key**, e.g. `NNSXS.XXXXXXXX...`

> Replace `YOUR_APP_ID` and `NNSXS.XXXXXXXX...` with your own values.  
> Do not hardcode your real password into public repositories.

### 5.2 Node-RED MQTT configuration

In the **Node-RED add-on** in Home Assistant:

1. Open the Node-RED editor.
2. Configure an **MQTT broker** node with:

   - **Server**: `eu1.cloud.thethings.network`
   - **Port**: `1883`
   - **Protocol**: MQTT v3.1.1
   - **Username**: `YOUR_APP_ID@ttn`
   - **Password**: `YOUR_TTN_MQTT_PASSWORD` (API key)
   - TLS: optional (configure according to TTN docs if you enable it).

3. The example flow subscribes to TTN uplinks using:

   ```text
   v3/YOUR_APP_ID@ttn/devices/+/up
   ```

   This pattern matches uplink messages from **all devices** in your
   application.

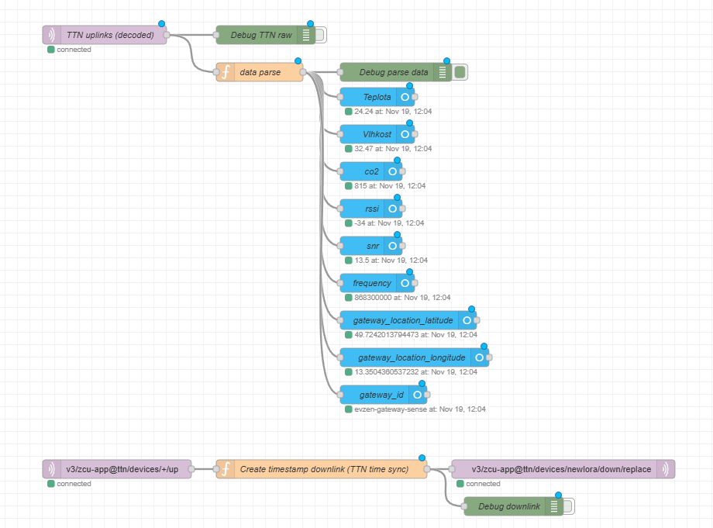
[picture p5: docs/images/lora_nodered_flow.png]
NodeRed flow
   

---

## 6. Node-RED flow: `lora_ttn_ha_flow.json`

This repository contains an example Node-RED flow in:

```text
home_assistant/lora/lora_ttn_ha_flow.json
```

Import it into Node-RED (menu → Import → paste JSON). Then adjust:

- MQTT broker settings (host, username, password)
- TTN Application ID (where relevant)
- Device-specific details if needed

### 6.1 What the flow does

The flow consists of three logical parts:

1. **MQTT input from TTN**  
   One or more **MQTT in** nodes subscribe to TTN topics, typically:

   - `v3/YOUR_APP_ID@ttn/devices/+/up` – for **uplinks**
   - Optionally `#` – for debugging all traffic

   The payload from TTN is a JSON object (`msg.payload`) with fields such as:

   - `uplink_message.decoded_payload.temperature`
   - `uplink_message.decoded_payload.humidity`
   - `uplink_message.decoded_payload.co2`
   - `uplink_message.rx_metadata[0].rssi`
   - `uplink_message.rx_metadata[0].snr`
   - `uplink_message.rx_metadata[0].gateway_ids.gateway_id`
   - `uplink_message.settings.frequency`
   - etc.

2. **Function node: `data parse`**  
   The function node:

   - Accepts both **TTN uplink JSON** and a simple HTTP JSON format
     (`{ temperature, humidity, co2 }`) for flexibility.
   - Ignores special packets with `frm_payload === "EQ=="` used by the
     optional time-sync mechanism.
   - Extracts and normalizes fields into a local `next` state:

     - `temperature`
     - `humidity`
     - `co2`
     - `rssi`
     - `snr`
     - `frequency`
     - `spreading_factor`
     - `bandwidth`
     - `gateway_id`
     - `gateway_eui`
     - `gateway_location` `{ latitude, longitude }`

   - Stores the most recent state in Node-RED **context** so that partial
     updates keep previous values.
   - Outputs a simplified `msg.payload` object for Home Assistant:

     ```json
     {
       "temperature": 23.4,
       "humidity": 42.1,
       "co2": 650,
       "rssi": -89,
       "snr": 7.5,
       "frequency": 868.3,
       "gateway_id": "your-gateway-id",
       "gateway_location": {
         "latitude": 50.0,
         "longitude": 14.0
       }
     }
     ```

3. **Home Assistant sensors (Node-RED Companion)**  
   The flow uses `node-red-contrib-home-assistant-websocket` nodes
   (`ha-sensor`) to publish the parsed values as **Home Assistant entities**.

   You should end up with entities like:

   - `sensor.lora_temperature` (°C)
   - `sensor.lora_humidity` (%)
   - `sensor.lora_co2` (ppm)
   - `sensor.lora_rssi` (dBm)
   - `sensor.lora_snr` (dB)
   - `sensor.lora_frequency` (Hz)
   - `sensor.lora_gateway_latitude`
   - `sensor.lora_gateway_longitude`
   - `sensor.lora_gateway_id`

   In Home Assistant, these will appear under a device such as
   **“Node-RED”** or **“Node-RED Companion”**, depending on how you
   configured the integration.

---

## 7. Optional: time synchronization via TTN downlink

The flow also contains an **optional** part that demonstrates how to use
TTN downlinks to synchronize the node's **RTC (Real-Time Clock)**:

- The node sends a special uplink with `frm_payload === "EQ=="` to request
  time.
- A Node-RED function node (`create timestamp`) listens to

  ```text
  v3/YOUR_APP_ID@ttn/devices/+/up
  ```

  and, when it sees that special payload, generates a 4-byte UNIX timestamp.

- The timestamp is encoded as base64 and sent back as a downlink using an
  MQTT topic of the form:

  ```text
  v3/YOUR_APP_ID@ttn/devices/YOUR_DEVICE_ID/down/replace
  ```

- The LocuSense node receives the downlink on the configured FPort and
  updates its internal RTC.

This mechanism is optional but useful if you want the node’s clock to be
synchronized without NTP or other external time sources.

---

## 8. Home Assistant: visualizing LoRa data

Once the flow is deployed and the node is active, you should see new
entities in **Home Assistant → Settings → Devices & Services → Devices**,
under the Node-RED device (or similar).

Typical entities:

- `sensor.lora_temperature`
- `sensor.lora_humidity`
- `sensor.lora_co2`
- `sensor.lora_rssi`
- `sensor.lora_snr`
- `sensor.lora_frequency`
- `sensor.lora_gateway_latitude`
- `sensor.lora_gateway_longitude`
- `sensor.lora_gateway_id`

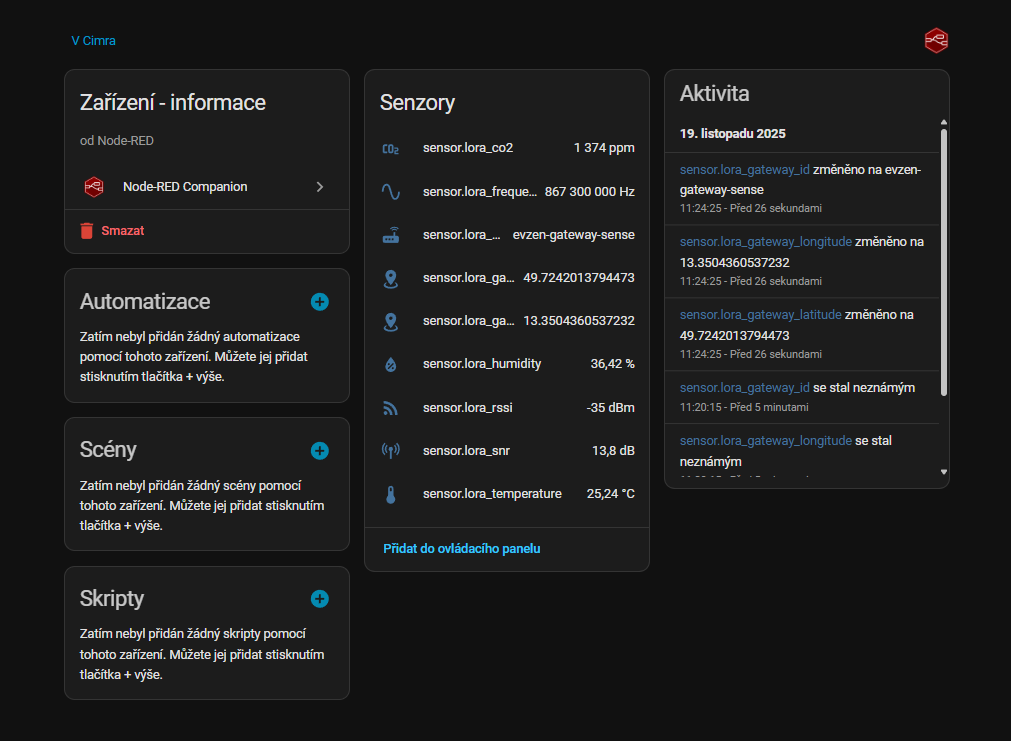
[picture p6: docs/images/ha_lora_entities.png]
Matter device


You can then build a Lovelace dashboard view similar to the example used for
the Matter/Thread device, for example:

- line graphs for temperature / humidity / CO₂
- a gauge for CO₂ (e.g. 350–2500 ppm range)
- tiles showing RSSI/SNR and gateway information

If you keep both Matter and LoRa integrations in the same Home Assistant
instance, you can create a separate **“Lora”** view and compare both data
paths on one dashboard.

---

## 9. Tips & troubleshooting

- If you see uplinks in TTN but nothing in Node-RED:
  - check the MQTT credentials (username / API key)
  - verify the MQTT server: `eu1.cloud.thethings.network:1883`
  - make sure the MQTT in node subscribes to
    `v3/YOUR_APP_ID@ttn/devices/+/up`.
- If Node-RED receives messages but Home Assistant shows no entities:
  - open Node-RED debug nodes to see parsed payloads
  - check the Home Assistant server configuration in the
    `node-red-contrib-home-assistant-websocket` nodes
  - confirm that the Node-RED add-on has access to Home Assistant's WebSocket
    API.
- If CO₂, temperature or humidity appear as `0` or `null`:
  - verify the TTN payload formatter
  - check that the node really sends the payload on **FPort 8**.

With this setup you get a complete LoRaWAN → TTN → MQTT → Node-RED →
Home Assistant pipeline, fully integrated into your LocuSense ecosystem.

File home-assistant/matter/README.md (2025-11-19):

# Home Assistant integration (Matter over Thread)

This document describes how to integrate the **LocuSense environmental node** as a  
**Matter over Thread device** into Home Assistant and how to build a dashboard with  
history, InfluxDB and Grafana visualization.

> ℹ️ LoRaWAN / TTN integration is documented separately in the
> [Home Assistant LoRaWAN guide](../lora/README.md).

> 🔧 Firmware details for the STM32 baseboard and ESP32-C6 bridge live in
> [`firmware/stm32/README.md`](../../firmware/stm32/README.md) and
> [`firmware/esp32c6/README.md`](../../firmware/esp32c6/README.md). Visit those before commissioning
> if you need to rebuild or adjust either MCU.

### Repository assets in this folder

- `matter_dashboard.yaml` – full Lovelace dashboard referenced in section 5.
- `../../docs/images/*.png` – screenshots embedded below (kept in the shared docs folder).

---

## 1. Prerequisites

You will need:

- A running **Home Assistant** instance (OS / Supervised recommended).
- **Home Assistant Connect ZBT-1** (or equivalent Thread border router) properly set up.
- The LocuSense node configured as a **Matter over Thread environmental sensor**
  (ESP32-C6 firmware flashed and working).
- In the configuration console run `SET comms_mode 2` (value `COMMS_MATTER`)
  so that the STM32 side speaks to the ESP32-C6 co-processor.
- Optional but recommended:
  - **InfluxDB** add-on (for long-term storage)
  - **Grafana** add-on (for nice charts, embedded into Home Assistant)
  - Optional remote access via **Cloudflared** (HTTPS tunnel / reverse proxy)

---

## 2. Create and verify a Thread network

If you are using **Home Assistant Connect ZBT-1**, follow the official guides:

- Forming a Thread network with Connect ZBT-1  
  – see the vendor guide (Nabu Casa) for **forming a new Thread network**.
- Home Assistant docs: **Thread integration** and adding Thread devices.  

Make sure that after setup you can see a **Thread network** under:

> **Settings → Devices & services → Thread**

Check that:

- The ZBT-1 is **Online**.
- At least one **Thread network** is listed and **Active**.
- The ESP32-C6 node is in radio range of the border router.

---

## 3. Commission the LocuSense Matter device

The ESP32-C6 module exposes LocuSense as a **Matter environmental sensor** with
CO₂, temperature, humidity, air quality and dual-battery monitoring.

1. Put the device into **Matter commissioning mode**  
   (see `firmware/esp32c6/README.md` for the exact button/command).  
   Typically you will either:
   - Scan a **Matter QR code** shown on the E-Ink display / label, or  
   - Use a **numeric setup code**.
   - In the STM32 console you can confirm radio selection with `SHOW`
     (look for `comms_mode = COMMS_MATTER`) before attempting commissioning.

2. In Home Assistant, go to:

   > **Settings → Devices & services → Add integration → Matter**

3. Follow the on-screen wizard:
   - Select **Add Matter device**.
   - Scan the QR code or enter the pairing code.
   - Wait for the onboarding to finish and the device to appear.

4. After pairing, you should see a new device (e.g. `Test product`) with several entities
   (sensors and binary sensors).

---

## 4. Exposed entities (example)

The exact entity IDs will depend on your Matter firmware and HA naming, but a typical
setup exposes:

| Function | Example entity ID | Notes |
|---|---|---|
| Temperature | `sensor.test_product_temperature` | °C |
| Relative humidity | `sensor.test_product_humidity` | % |
| CO₂ concentration | `sensor.test_product_carbon_dioxide` | ppm |
| Air quality index / category | `sensor.test_product_air_quality` | Numeric or descriptive |
| Li-Ion battery status (OK/fault) | `binary_sensor.test_product_battery_5` | `on` = active / fault depends map  |
| Li-Ion battery voltage | `sensor.test_product_battery_voltage_5` | V |
| Li-SoCl₂ battery status | `binary_sensor.test_product_battery_6` | Backup / long-term battery |
| Li-SoCl₂ battery voltage | `sensor.test_product_battery_voltage_6` | V |
| Charge state (Li-Ion) | `sensor.test_product_battery_charge_state` | e.g. Charging / Charged / No USB |

> Adjust the entity IDs in the examples below to match what you see in  
> **Settings → Devices & services → [your device] → Entities**.

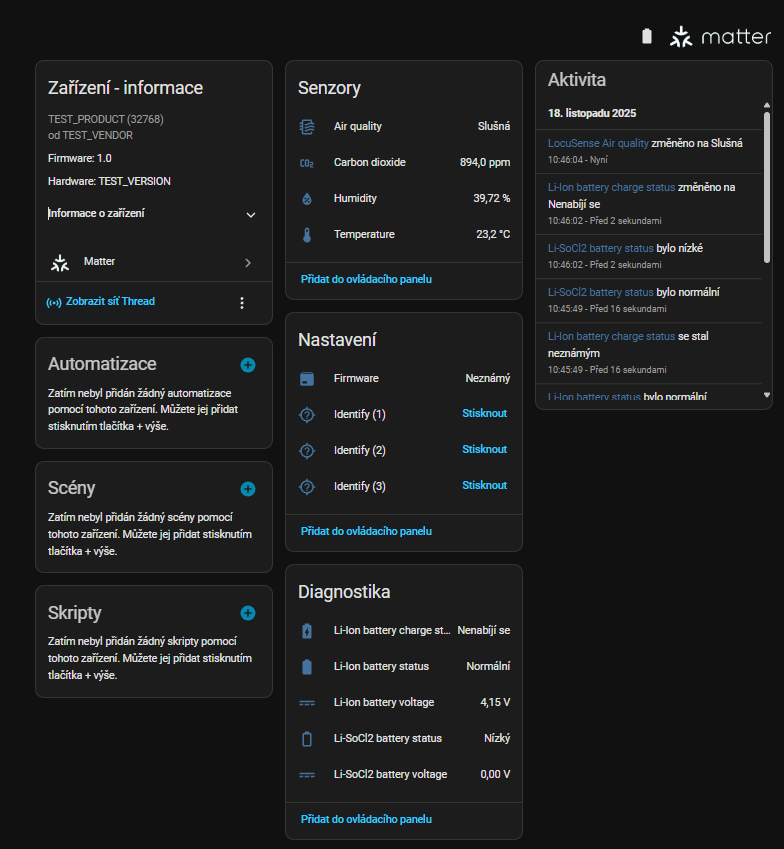
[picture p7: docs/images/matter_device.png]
Matter device


---

## 5. Example Matter dashboard in Home Assistant

You can build a dedicated **Matter / Thread** view showing:

- Current CO₂, temperature, humidity, air quality.
- Battery state (Li-Ion + Li-SoCl₂).
- Short-term history of all values.
- Optional media player (e.g. Google Nest Hub) to visualize the data in the room.
- Embedded **Grafana** panels for more advanced charts.

### 5.1 Dashboard YAML

A complete example dashboard configuration is provided in:

> `home-assistant/matter_dashboard.yaml`

To use it:

1. In Home Assistant, create a new dashboard (or edit an existing one).
2. Click **⋮ → Edit dashboard → Raw configuration editor**.
3. Paste the content of `matter_dashboard.yaml` (adjust entity IDs as needed).
4. Save and reload the dashboard.

The example view includes:

- A digital clock
- Line graphs for:
  - `sensor.test_product_temperature`
  - `sensor.test_product_humidity`
- A CO₂ gauge:
  - Min: 350 ppm  
  - Max: 2500 ppm  
  - Green: 0–1000 ppm, Yellow: 1000–1500 ppm, Red: 1500+ ppm
- Tiles for all main sensors and batteries:
  - Temperature, humidity, CO₂, air quality
  - Li-Ion and Li-SoCl₂ battery status and voltage
  - Li-Ion charge state + history graph for charge state
- A second view for LoRa (if you use the LoRa node) is defined in the same file,  
  but is independent of Matter and can be removed if not needed.

---

## 6. InfluxDB integration

To store sensor values long-term, enable the **InfluxDB** add-on and configure
the Home Assistant integration.

### 6.1 Add-on configuration (example)

You can configure the InfluxDB add-on with TLS and authentication,
for example:

```yaml
auth: true
reporting: true
ssl: true
certfile: fullchain.pem
keyfile: privkey.pem
envvars: []
```

> ⚠️ Use your own certificates and credentials.  
> The exact paths and options depend on your environment.

### 6.2 `configuration.yaml` for InfluxDB

In your Home Assistant `configuration.yaml` add something like:

```yaml
influxdb:
  host: a0d7b954-influxdb
  port: 8086
  database: homeassistant
  username: YOUR_USERNAME
  password: YOUR_PASSWORD
  max_retries: 3
  default_measurement: state
```

- `host` can be the internal container name (e.g. when using HA OS add-ons) or
  the host running InfluxDB.
- Change the credentials and database name to your own.

For a more detailed walkthrough of integrating **Home Assistant + InfluxDB + Grafana**,  
see this guide:

- https://www.influxdata.com/blog/how-integrate-gafana-home-assistant/

---

## 7. Grafana integration

Grafana is used to visualize the time-series data from InfluxDB and embed
the charts as panels in the Home Assistant dashboard.

### 7.1 Local-only Grafana (no Cloudflare)

If you run Grafana **only on the local network**, the add-on can be configured
with a minimal set of environment variables such as:

```yaml
env_vars:
  - name: GF_SECURITY_ALLOW_EMBEDDING
    value: "true"
  - name: GF_AUTH_ANONYMOUS_ENABLED
    value: "true"
  - name: GF_AUTH_ANONYMOUS_ORG_ROLE
    value: Viewer
  - name: GF_SERVER_ROOT_URL
    value: http://homeassistant:3000/
  - name: GF_SERVER_SERVE_FROM_SUB_PATH
    value: "false"
plugins:
  - yesoreyeram-boomtheme-panel
custom_plugins: []
ssl: false
```

Notes:

- `GF_SECURITY_ALLOW_EMBEDDING` must be `true` to allow `<iframe>` embedding.
- `GF_AUTH_ANONYMOUS_ENABLED` lets the HA dashboard access Grafana without login
  (for the Viewer role only).
- Adjust `GF_SERVER_ROOT_URL` to match how you access Grafana from Home Assistant
  (`http://<your-ip>:3000/` or similar).
- Disable SSL (`ssl: false`) if you only use HTTP locally.

### 7.2 Optional: Grafana via Cloudflare tunnel

If you expose Grafana **publicly** through a tunnel / reverse proxy (e.g. the
**Cloudflared** add-on), you can set up something like:

```yaml
env_vars:
  - name: GF_SECURITY_ALLOW_EMBEDDING
    value: "true"
  - name: GF_AUTH_ANONYMOUS_ENABLED
    value: "true"
  - name: GF_AUTH_ANONYMOUS_ORG_NAME
    value: Main Org.
  - name: GF_AUTH_ANONYMOUS_ORG_ROLE
    value: Viewer
  - name: GF_SERVER_ROOT_URL
    value: https://grafana.example.com/
  - name: GF_SERVER_SERVE_FROM_SUB_PATH
    value: "false"
  - name: GF_SECURITY_ADMIN_USER
    value: admin
  - name: GF_SECURITY_ADMIN_PASSWORD
    value: STRONG_PASSWORD
  - name: GF_AUTH_DISABLE_LOGIN_FORM
    value: "false"
  - name: GF_SECURITY_COOKIE_SECURE
    value: "true"
  - name: GF_SECURITY_COOKIE_SAMESITE
    value: none
plugins:
  - yesoreyeram-boomtheme-panel
custom_plugins: []
ssl: true
certfile: fullchain.pem
keyfile: privkey.pem
```

And a Cloudflared configuration like:

```yaml
external_hostname: home.example.com
additional_hosts:
  - hostname: grafana.example.com
    service: http://a0d7b954-grafana:3000
```

> 🔒 If you expose Grafana to the internet, treat this as a development example only.  
> Use strong credentials, consider disabling anonymous access or restricting access
> to a VPN / specific IPs.

---

## 8. Embedding Grafana panels into Home Assistant

In the dashboard YAML (`matter_dashboard.yaml`) you can include Grafana panels as
`iframe` cards, for example:

```yaml
- type: iframe
  url: >-
    https://grafana.example.com/d-solo/YOUR_DASH_ID/your-panel
    ?orgId=1&panelId=1&from=now-1h&to=now&refresh=30s&kiosk=tv
  aspect_ratio: 45%
  card_mod:
    style: |
      :host {
        --ha-card-background: transparent;
      }
      ha-card {
        background: transparent !important;
        box-shadow: none !important;
      }
      ha-card > div,
      ha-card .card-content,
      ha-card iframe {
        background: transparent !important;
      }
```

You can also use a custom card such as `custom:addon-iframe-card` if you prefer,
as shown in the example YAML.

Make sure that:

- The **URL** matches your Grafana instance (local or tunneled).
- Grafana allows embedding (`GF_SECURITY_ALLOW_EMBEDDING=true`).
- Either anonymous access is enabled (Viewer role) or the iframe can authenticate.

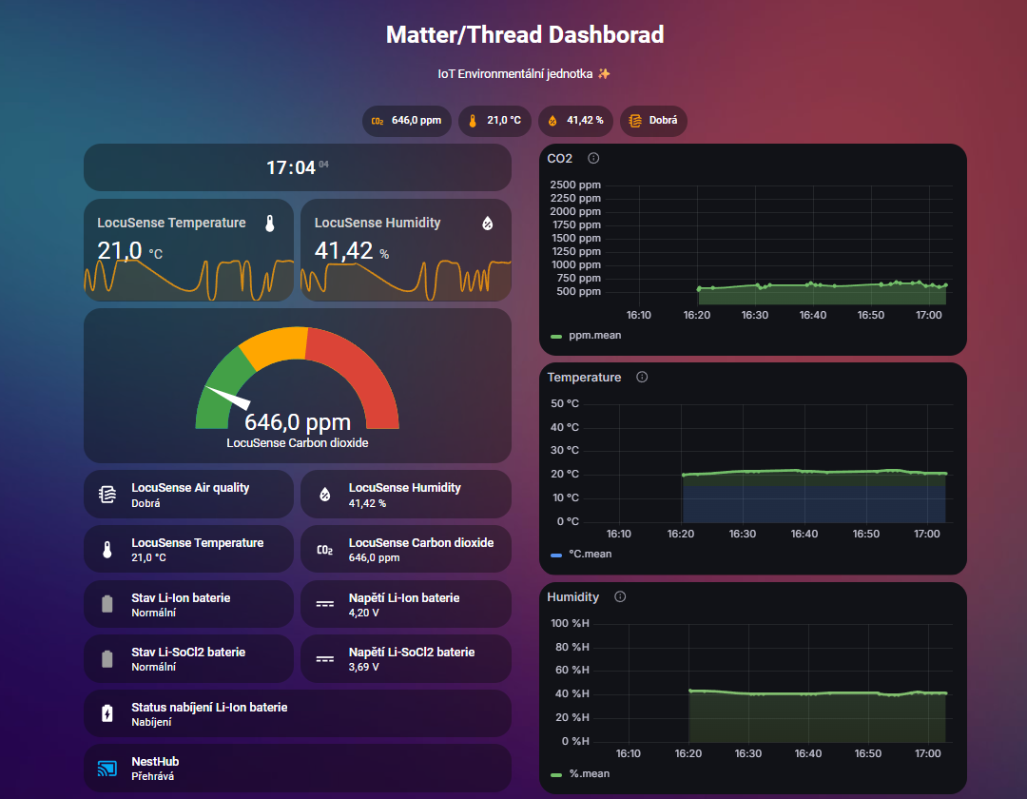
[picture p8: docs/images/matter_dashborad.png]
Matter dashboard


---

## 9. Security and best practices

- Change all example usernames and passwords to your own.
- Use HTTPS and valid certificates for any externally exposed service.
- If you use anonymous Grafana access, keep it **read-only** and only for the
  organization/boards you actually want visible.
- Home Assistant, InfluxDB and Grafana should ideally live on a trusted network
  or behind a VPN if they hold sensitive sensor data.

---

## 10. Troubleshooting

**Matter device not visible in Home Assistant**

- Check that the Thread network is active and that Connect ZBT-1 is online.
- Make sure the node is in commissioning mode and close enough to the border router.
- Try removing and re-adding the device in **Settings → Devices & services → Matter**.

**Entities have different names than in the examples**

- Open the device page in HA and confirm the actual entity IDs.
- Edit the dashboard YAML and replace `sensor.test_product_*` with your IDs.

**Grafana iframe shows a blank page**

- Verify you can open the Grafana URL in a browser from the same network.
- Check `GF_SECURITY_ALLOW_EMBEDDING` and `GF_AUTH_ANONYMOUS_ENABLED`.
- If using HTTPS, ensure the certificate is trusted by the device running the browser.

**InfluxDB has no data**

- Check the Home Assistant logs for `influxdb` errors.
- Validate `host`, `port`, credentials and `database` in `configuration.yaml`.
- Confirm that the InfluxDB add-on is running.

---

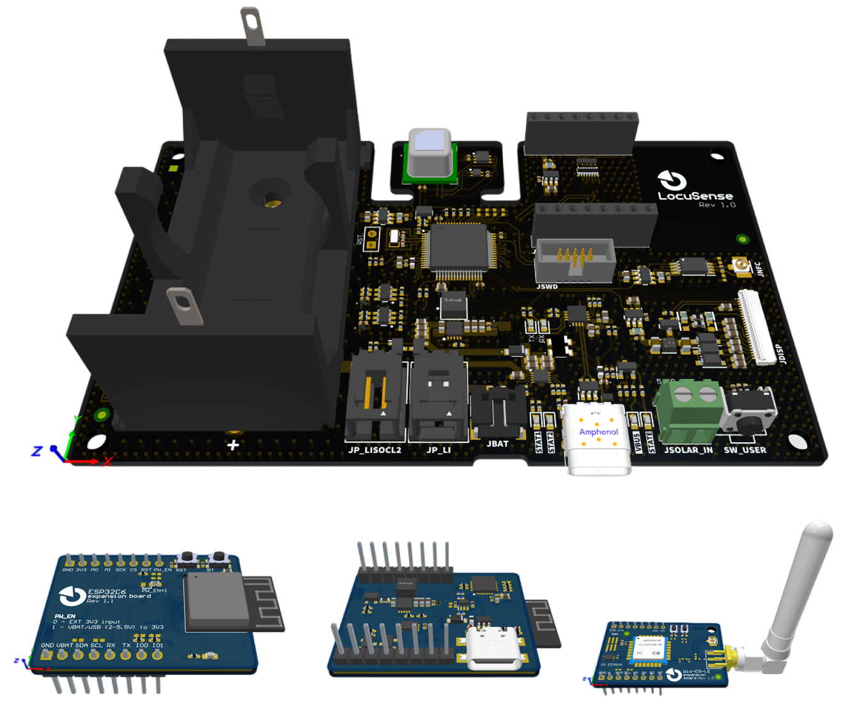
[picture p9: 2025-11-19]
docs/images/hardware_overview.png

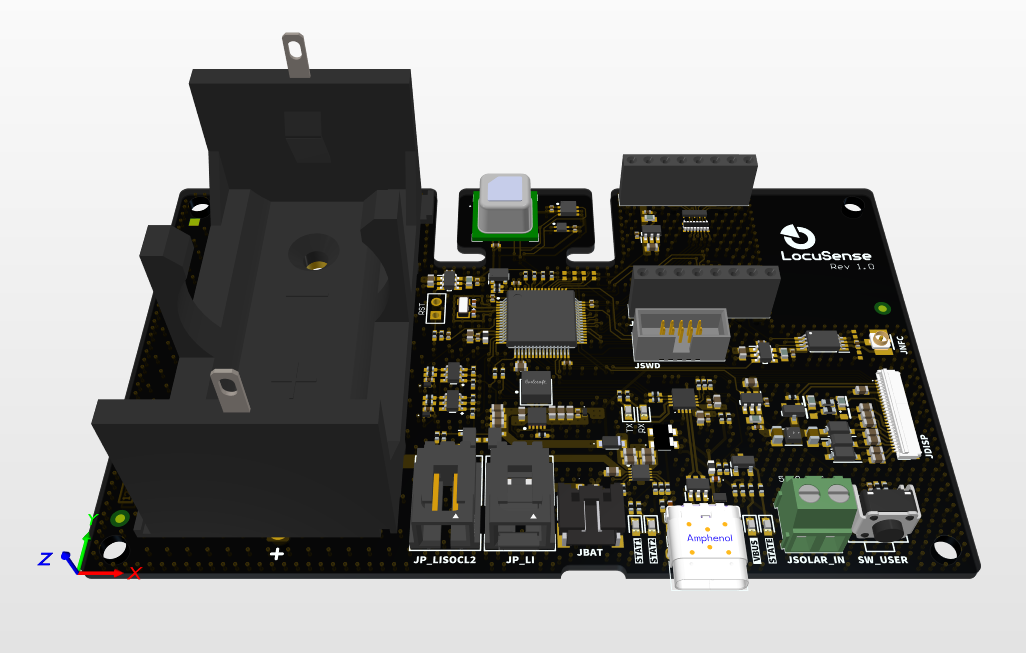
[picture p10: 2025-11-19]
docs/images/altium_mainboard.png

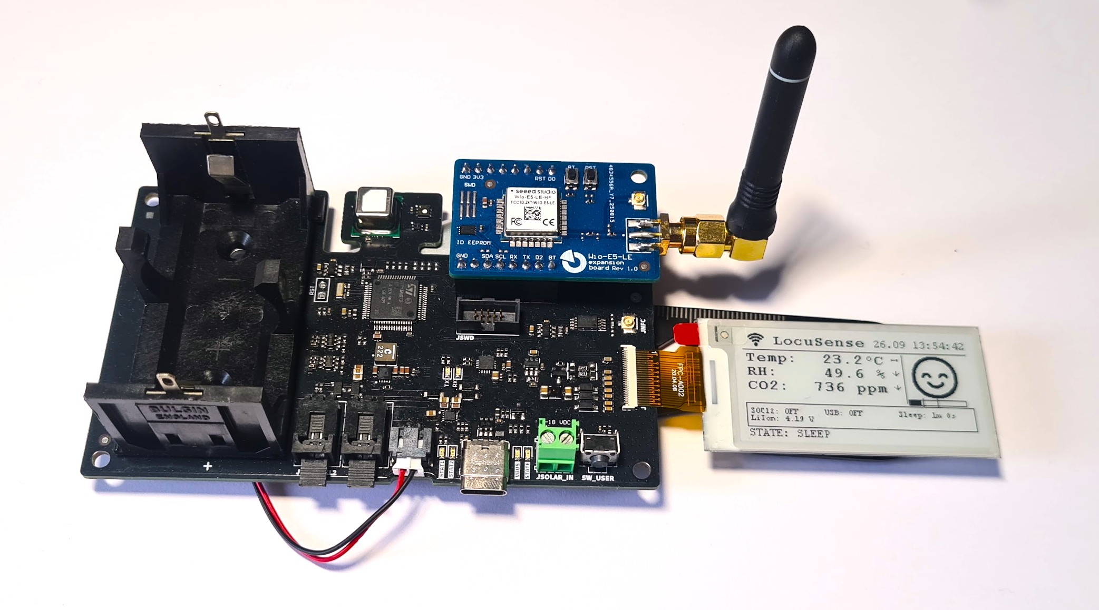
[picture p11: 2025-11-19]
docs/images/locusense_hw.jpg

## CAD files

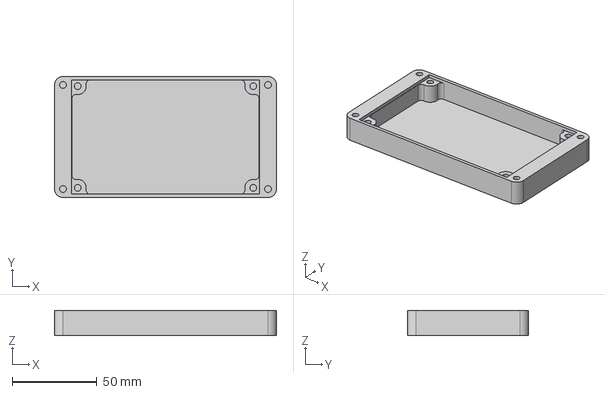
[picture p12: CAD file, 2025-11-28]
hardware/3D_model/BOT.step
130.9 x 71.4 x 15.0 mm

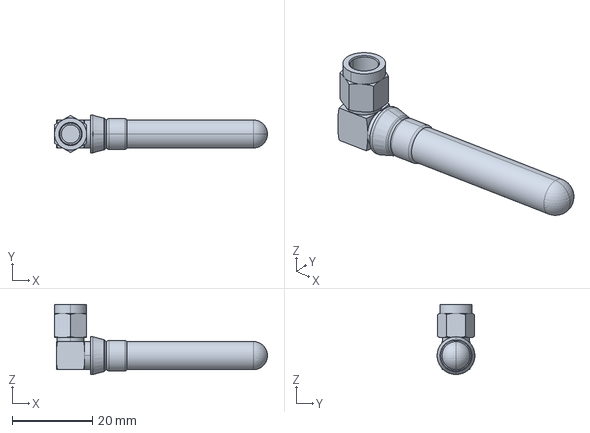
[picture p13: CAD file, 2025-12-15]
hardware/altium/LoraWIO_module/c-ant-868-cw-rcs-b-3d.stp
53.0 x 9.40 x 17.4 mm

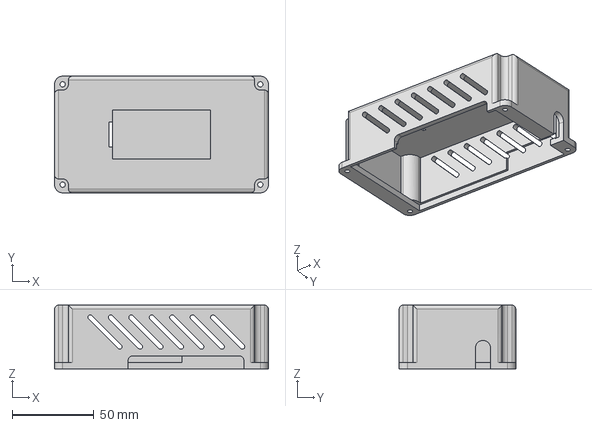
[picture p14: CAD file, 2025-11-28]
hardware/3D_model/TOP.step
130.9 x 71.4 x 39.0 mm

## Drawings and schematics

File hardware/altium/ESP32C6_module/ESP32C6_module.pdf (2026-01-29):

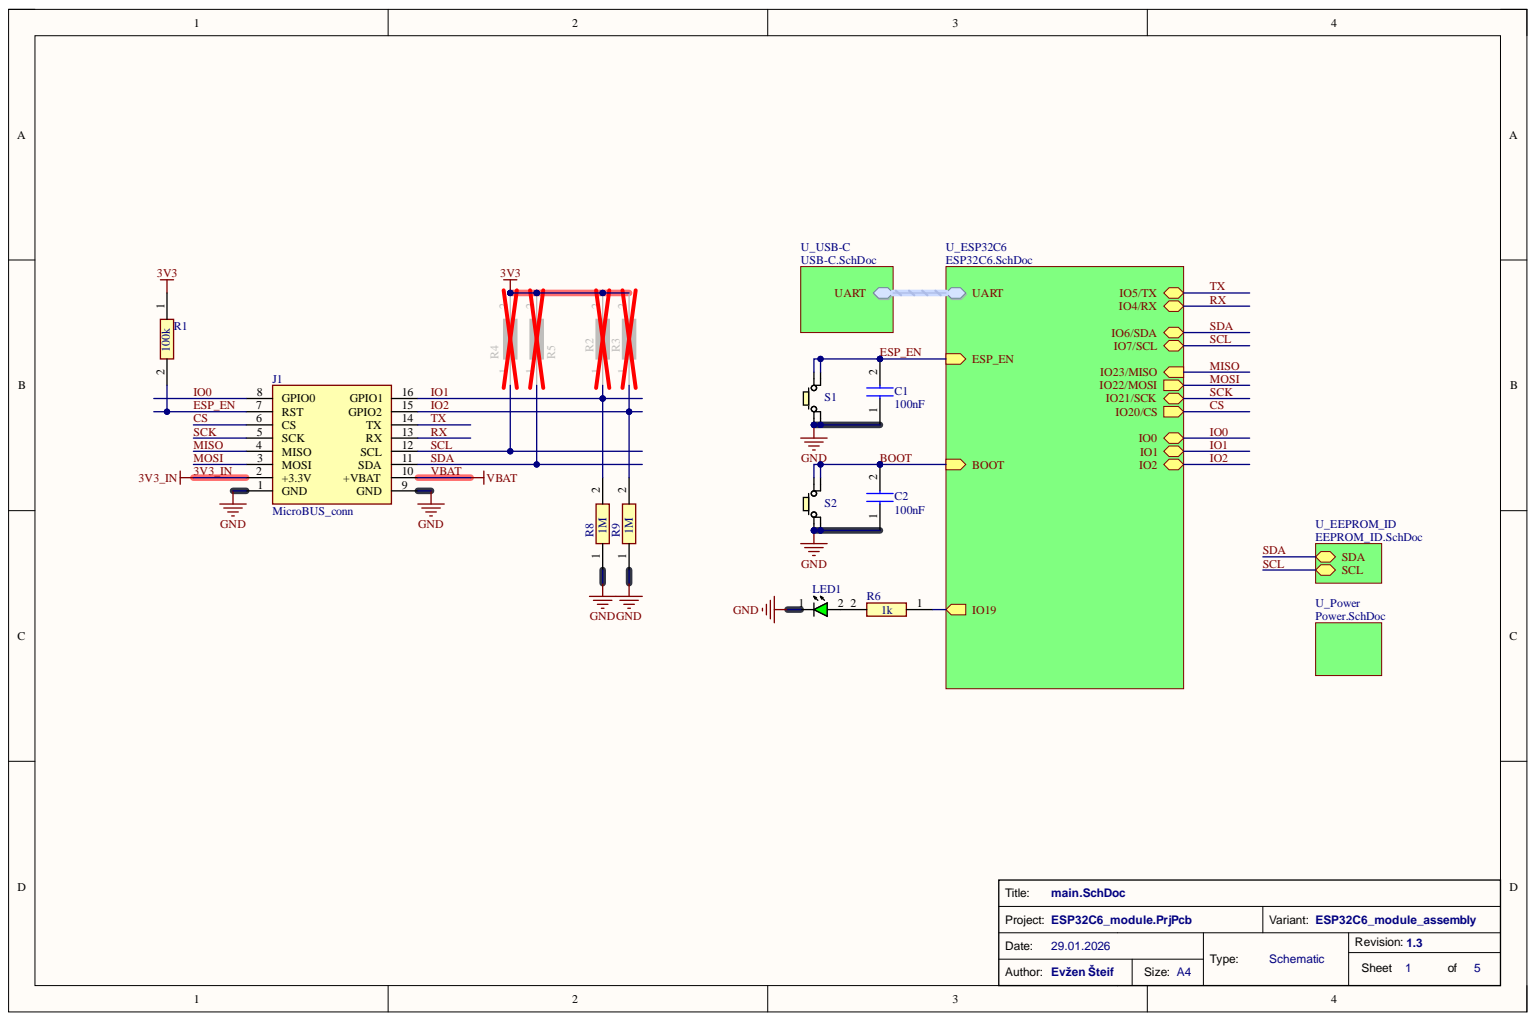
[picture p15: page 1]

Projec t : ESP32C6_mo d u le. P r j P c b | Variant : ESP32C6_mo d u le_asse m b l y

Dat e : 29.01.202 6 | Type : Schemat i c | Revisio n : 1. 3

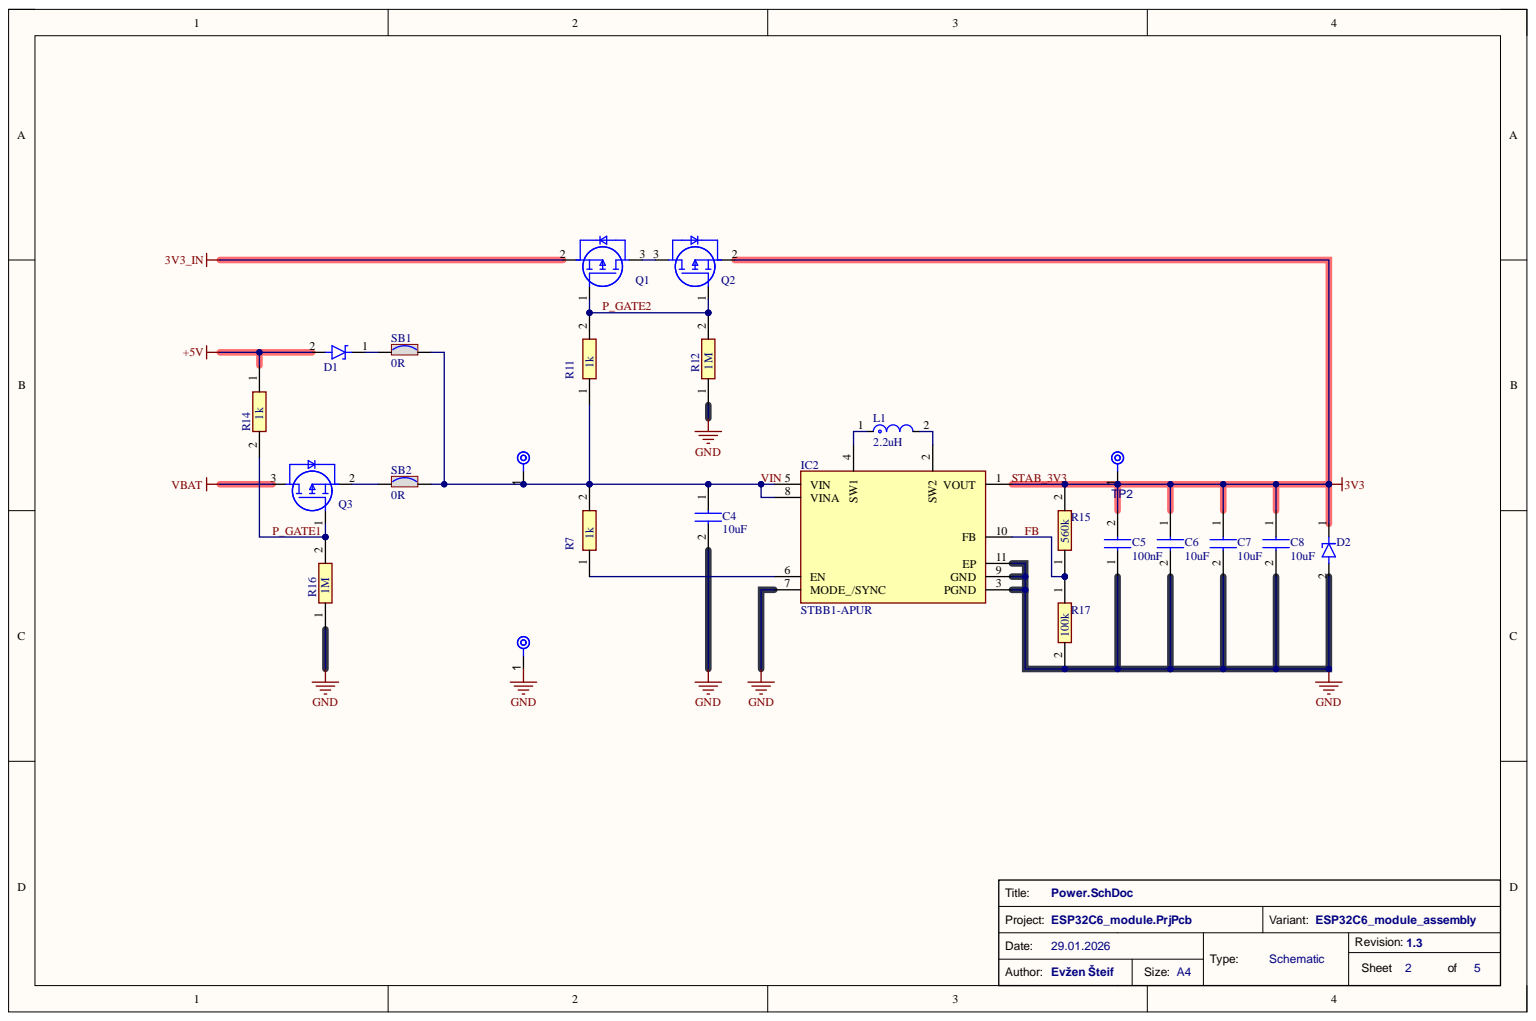
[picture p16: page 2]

1 1

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

Dat e : 29.01.202 6 | Type : Schemat i c | Revisio n : 1. 3

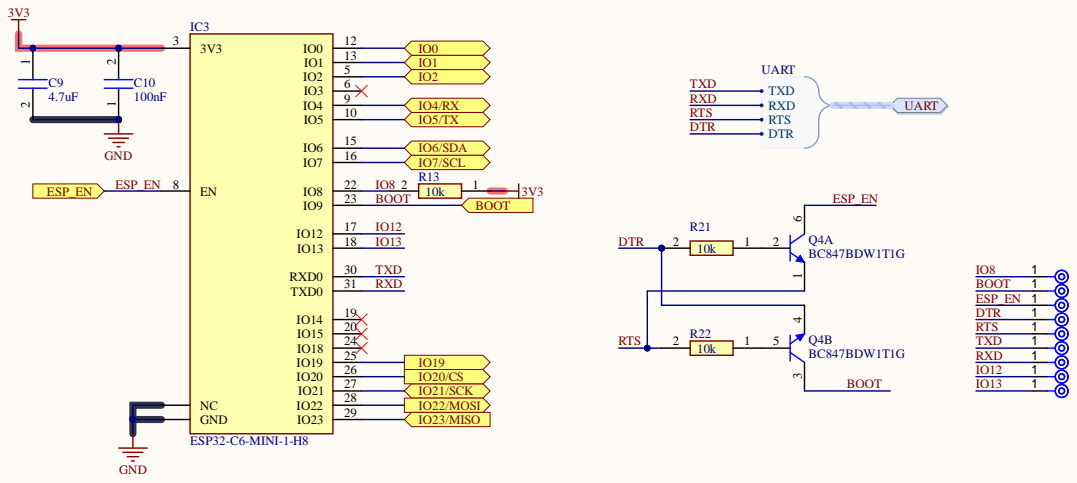
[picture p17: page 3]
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

Dat e : 29.01.202 6 | Type : Schemat i c | Revisio n : 1. 3

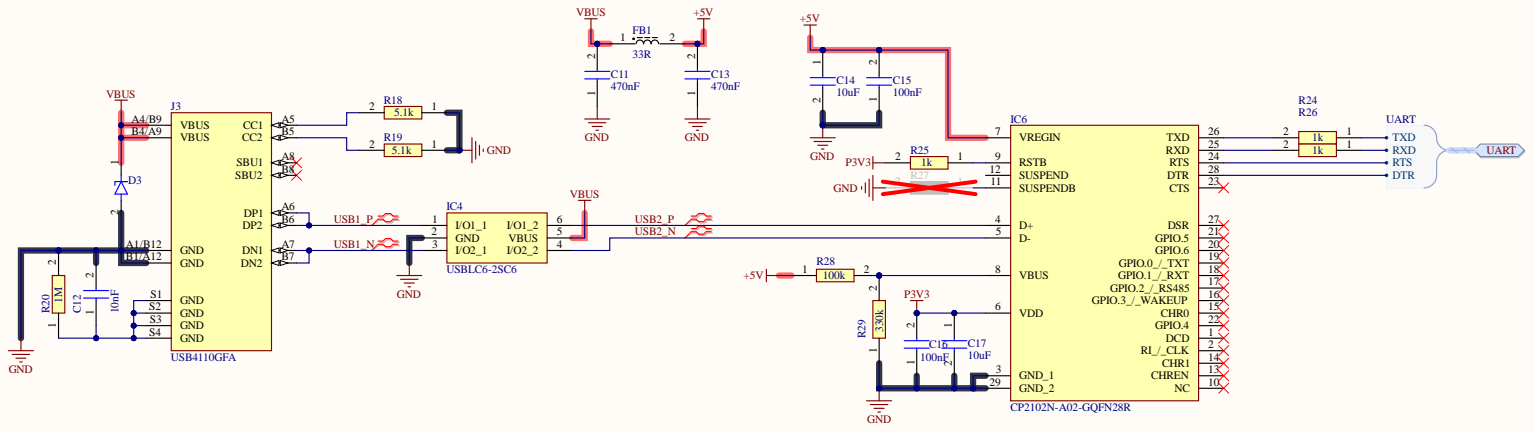
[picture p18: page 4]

USB1_P USB1_N 2 | | 5 | | 5

P roject E S P32C6_m d u le. P r j P c b | Var ian E S P32C6_m d u le_assem b l y

Dat 29.01.202 6 | Type Schemat i c | Revision: Sheet 1. 3

Š Autho r E v tei | S ize: A

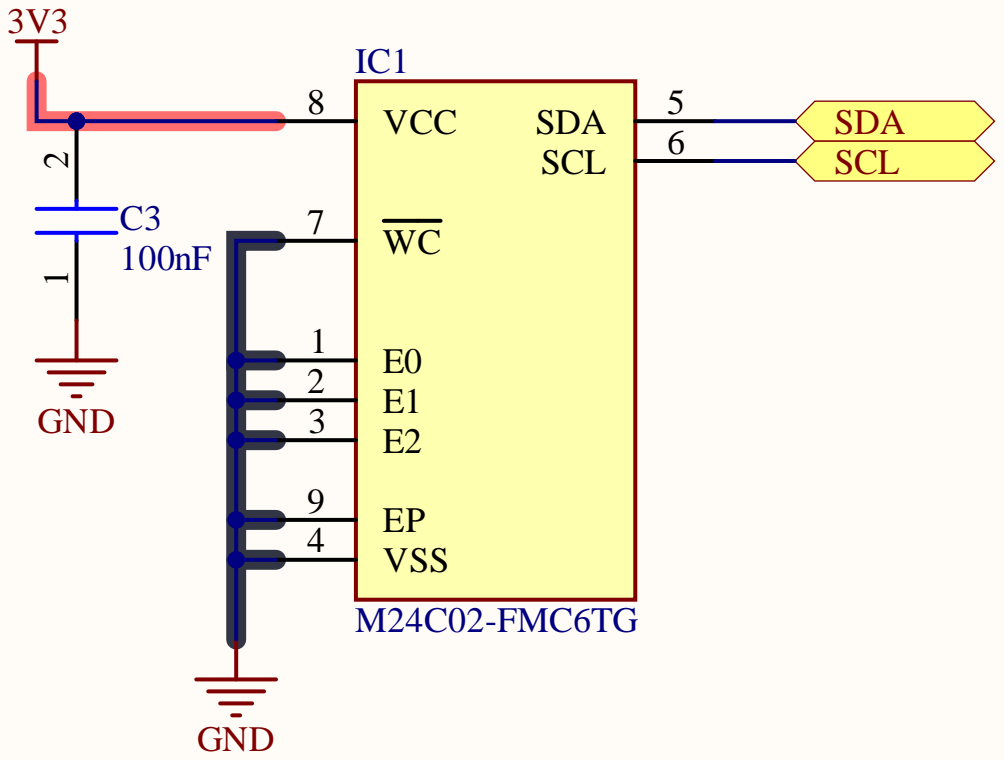
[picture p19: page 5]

Project: ESP32C6_module.PrjPcb | Variant: ESP32C6_module_assembly

Date: 29.01.2026 | Type: Schematic | Revision: 1.3

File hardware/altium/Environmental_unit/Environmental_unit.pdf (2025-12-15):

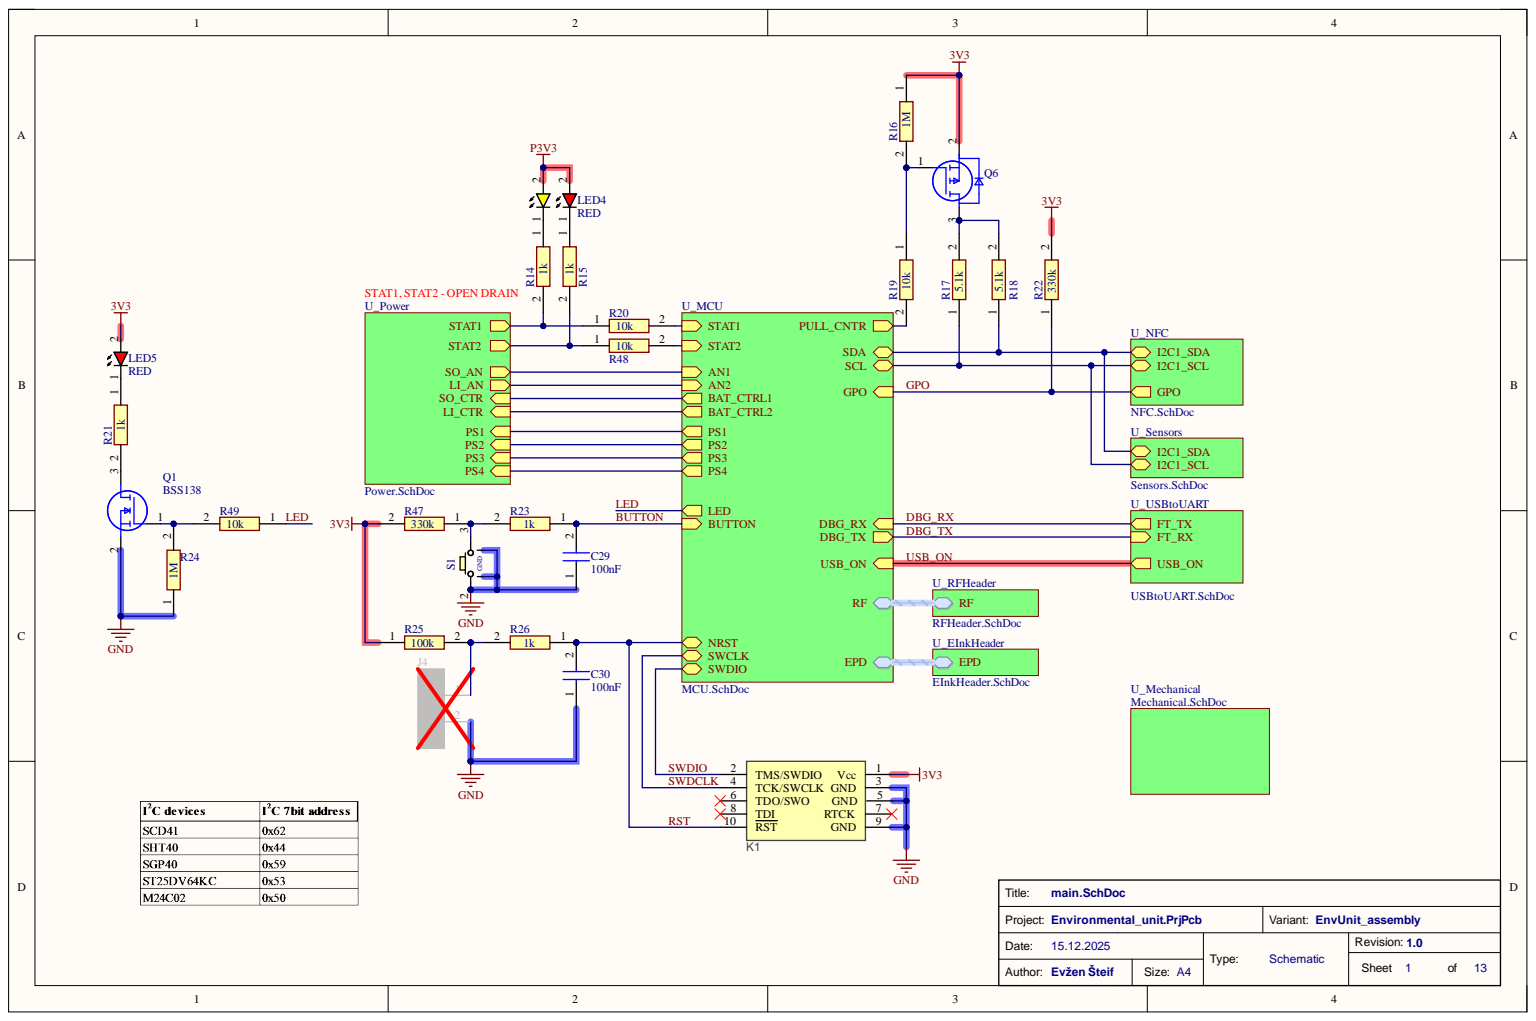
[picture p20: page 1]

Project: Environmental_unit.PrjPcb | Variant: EnvUnit_assembly

Date: 15.12.2025 | Type: Schematic | Revision: 1.0

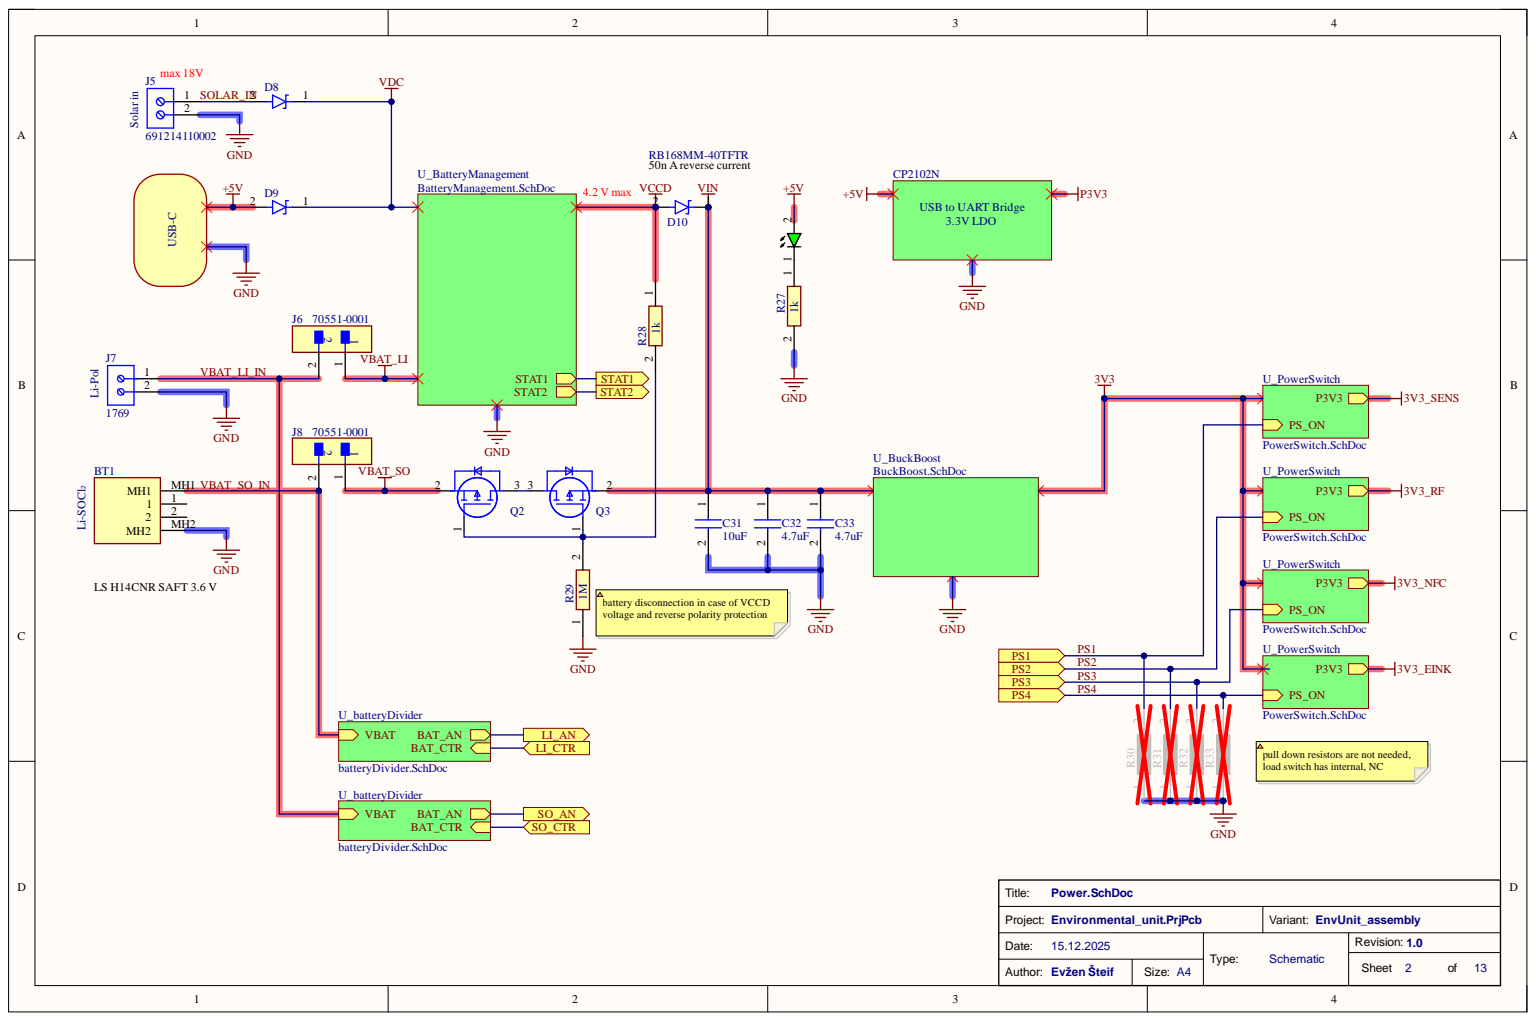
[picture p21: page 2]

PS1
PS2 | PS_ O N
PS3

tors are not ne
s int

Projec t : Envi r o nmental_u n i t . P r j P c b | Variant : EnvU n it_assem b l y

Dat e : 15.12.202 5 | Type : Schemat i c | Revisio n : 1. 0

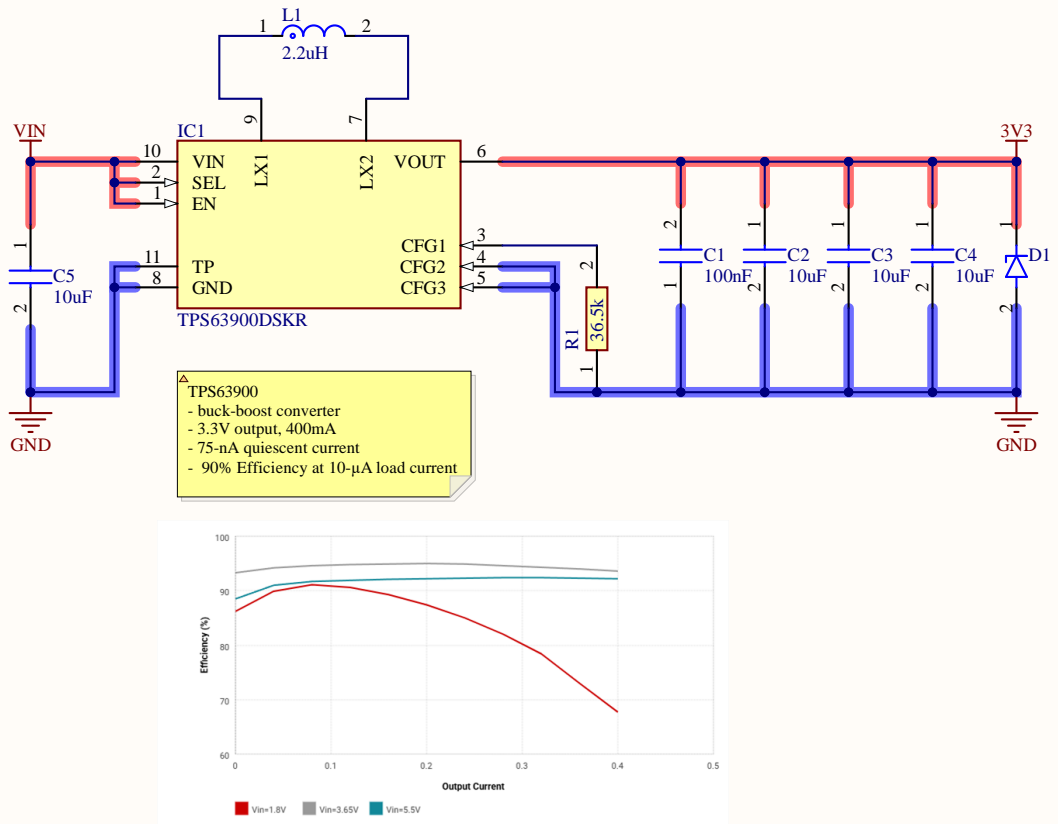
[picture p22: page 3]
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

Dat e : 15.12.202 5 | Type : Schemat i c | Revisio n : 1. 0

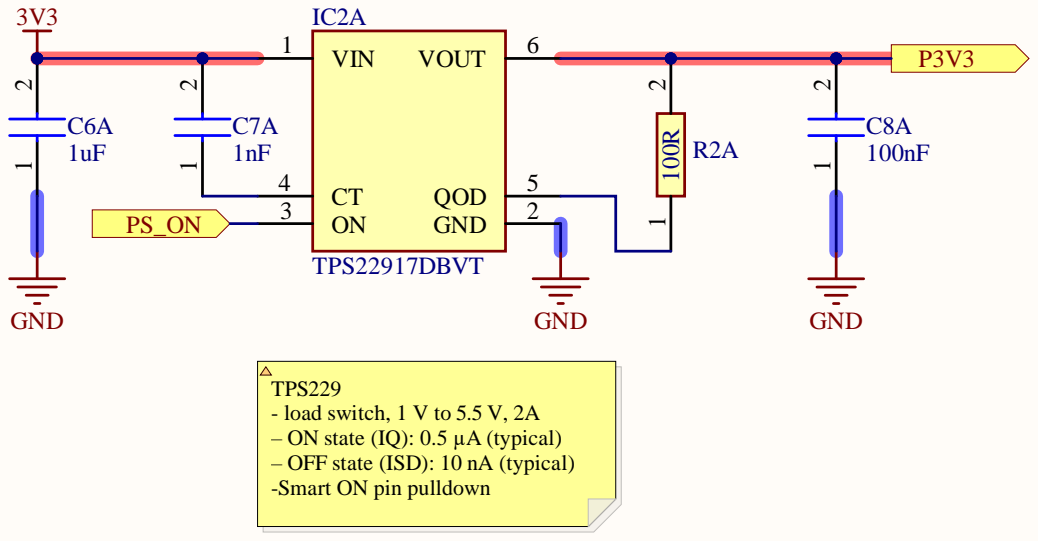
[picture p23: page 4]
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

Dat e : 15.12.202 5 | Type : Schemat i c | Revisio n : 1. 0

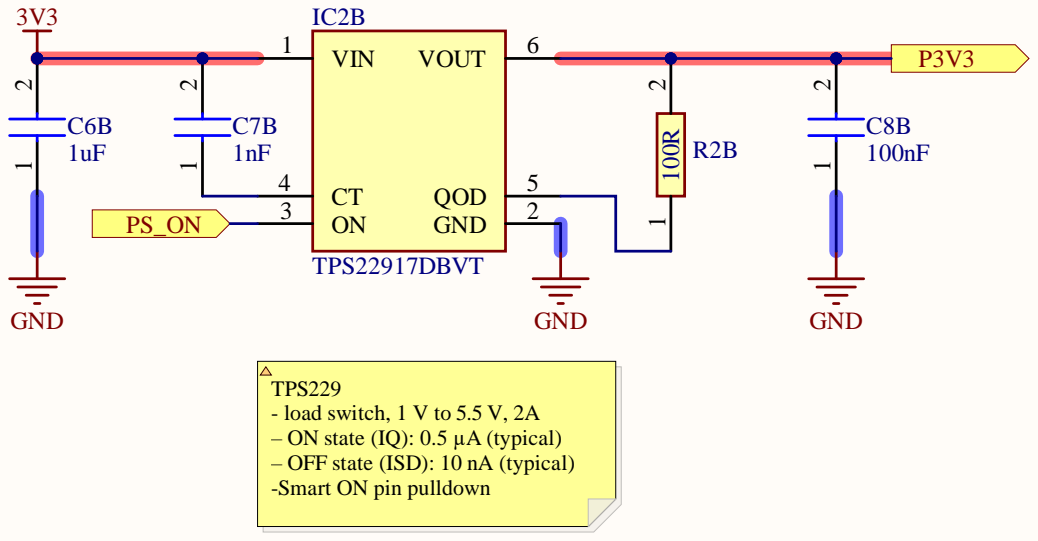
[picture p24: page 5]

TPS229
- load switch, 1 V to 5.5 V, 2A
– ON state (IQ): 0.5 µA (typical)
– OFF state (ISD): 10 nA (typical)
-Smart ON pin pulldown

Project: Environmental_unit.PrjPcb | Variant: EnvUnit_assembly

Date: 15.12.2025 | Type: Schematic | Revision: 1.0

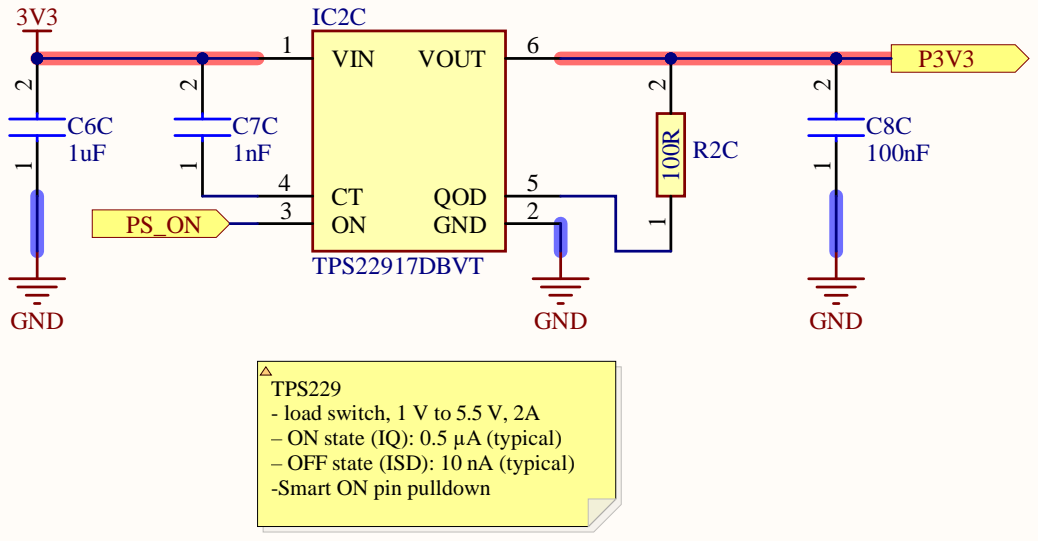
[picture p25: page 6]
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

Project: Environmental_unit.PrjPcb | Variant: EnvUnit_assembly

Date: 15.12.2025 | Type: Schematic | Revision: 1.0

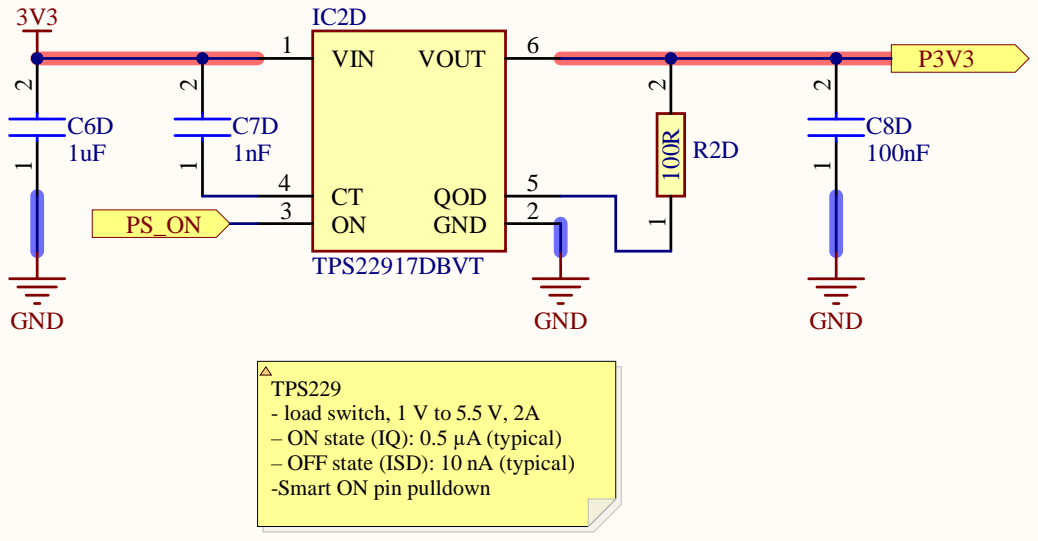
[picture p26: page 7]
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

Project: Environmental_unit.PrjPcb | Variant: EnvUnit_assembly

Date: 15.12.2025 | Type: Schematic | Revision: 1.0


ent current in Ba

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

Dat e : 15.12.202 5 | Type : Schemat i c | Revisio n : 1. 0

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

Dat e : 15.12.202 5 | Type : Schemat i c | Revisio n : 1. 0


Project: Environmental_unit.PrjPcb | Variant: EnvUnit_assembly

Date: 15.12.2025 | Type: Schematic | Revision: 1.0


3 2
6 4
4 8

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

Dat e : 15.12.202 5 | Type : Schemat i c | Revisio n : 1. 0

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

Dat e : 15.12.202 5 | Type : Schemat i c | Revisio n : 1. 0


A 7 2 | | 5 | | USB2 _N 5

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

Dat e : 15.12.202 5 | Type : Schemat i c | Revisio n : 1. 0

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

Dat e : 15.12.202 5 | Type : Schemat i c | Revisio n : 1. 0

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

Dat e : 15.12.202 5 | Type : Schemat i c | Revisio n : 1. 0


SCK DIN VGH VGL VCOM VSL VDD VSH2

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

Dat e : 15.12.202 5 | Type : Schemat i c | Revisio n : 1. 0

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

Dat e : 15.12.202 5 | Type : Schemat i c | Revisio n : 1. 0

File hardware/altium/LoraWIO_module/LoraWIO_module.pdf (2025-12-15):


Project: LoraWIO_module.PrjPcb | Variant: LoraWio_module_assembly

Date: 15.12.2025 | Type: Schematic | Revision: 1.0


Antenna:
ANT-868-CW-RCS-SMA

Project: LoraWIO_module.PrjPcb | Variant: LoraWio_module_assembly

Date: 15.12.2025 | Type: Schematic | Revision: 1.0


Project: LoraWIO_module.PrjPcb | Variant: LoraWio_module_assembly

Date: 15.12.2025 | Type: Schematic | Revision: 1.0

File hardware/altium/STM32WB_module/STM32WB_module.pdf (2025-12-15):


Project: STM32WB_module.PrjPcb | Variant: STM32WB_assembly

Date: 15.12.2025 | Type: Schematic | Revision: 1.0


6 | 1 6
1 5 | 3 1
1 7 | 5 7
3 2 | 6 0

Projec t : ST M32W B_mo d u l e . P r j P c b | Variant : ST M32W B_assem b l y

Dat e : 15.12.202 5 | Type : Schemat i c | Revisio n : 1. 0

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

Dat e : 15.12.202 5 | Type : Schemat i c | Revisio n : 1. 0


Project: STM32WB_module.PrjPcb | Variant: STM32WB_assembly

Date: 15.12.2025 | Type: Schematic | Revision: 1.0

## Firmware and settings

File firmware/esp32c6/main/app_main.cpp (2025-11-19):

/*
 * Matter Multi-Sensor with UART data from STM32 - TEXT PROTOCOL VERSION
 * Author: Evzen Steif
 *
 * Overview:
 *  - Exposes temperature, humidity, CO2 concentration and power source state as Matter endpoints.
 *  - Communicates with an STM32 over a simple ASCII UART "TEXT" protocol (DATA/STATUS/COMM/etc.).
 *  - Handles commissioning (QR/manual codes, open/close commissioning window) over UART commands.
 *  - Uses a WAKE/READY GPIO handshake and PM lock to cooperate with light sleep on an ESP32-C6 SED.
 */

#include <esp_err.h>
#include <esp_log.h>
#include <nvs_flash.h>
#include <driver/uart.h>
#include <driver/gpio.h>
#include <esp_sleep.h>
#include "driver/rtc_io.h"

#if CONFIG_PM_ENABLE
#include <esp_pm.h>
#endif

#include <esp_matter.h>
#include <esp_matter_ota.h>
#include <common_macros.h>
#include <app_priv.h>
#include <esp_rom_sys.h>
#include <freertos/FreeRTOS.h>
#include <freertos/task.h>

#if CHIP_DEVICE_CONFIG_ENABLE_THREAD
#include <platform/ESP32/OpenthreadLauncher.h>
#include <platform/ConnectivityManager.h>
#endif

#include <app/InteractionModelEngine.h>
#include <app/server/CommissioningWindowManager.h>
#include <app/server/Server.h>
#include <app-common/zap-generated/cluster-objects.h>

/* === Setup payload (QR/manual) & providers === */
#include <platform/DeviceInstanceInfoProvider.h>
#include <platform/CommissionableDataProvider.h>
#include <setup_payload/SetupPayload.h>
#include <setup_payload/ManualSetupPayloadGenerator.h>
#include <setup_payload/QRCodeSetupPayloadGenerator.h>

/* NEW: schedule work helpers */
#include <platform/PlatformManager.h>
#include <inttypes.h>
#include <stdarg.h>
#include <string.h>

#include <platform/ConfigurationManager.h>
using chip::DeviceLayer::ConfigurationMgr;

static void InitNodeBasicInformation()
{
    static constexpr char kSerialNumber[] = "ESP32C6-SED-000123";
    static constexpr char kManufacturingDate[] = "2025-11-01";
    (void)ConfigurationMgr().StoreSerialNumber(kSerialNumber, strlen(kSerialNumber));
    (void)ConfigurationMgr().StoreSoftwareVersion(10000); // e.g. 1.0.0 => 10000
    (void)ConfigurationMgr().StoreHardwareVersion(1);
    (void)ConfigurationMgr().StoreManufacturingDate(kManufacturingDate, strlen(kManufacturingDate));
}

static const char *TAG = "app_main";

using namespace esp_matter;
using namespace esp_matter::attribute;
using namespace esp_matter::endpoint;
using namespace chip::app::Clusters;
namespace DeviceEventType = chip::DeviceLayer::DeviceEventType;

/* ===== UART & GPIO config ===== */
#define UART_NUM       UART_NUM_1
#define UART_TX_PIN    GPIO_NUM_5
#define UART_RX_PIN    GPIO_NUM_4
#define UART_BAUD_RATE 9600
#define UART_BUF_SIZE  256
#define WAKE_PIN       GPIO_NUM_2
static constexpr gpio_num_t kReadyPin = GPIO_NUM_3;

/* App-level limits for basic sanity checking of sensor values */
static constexpr int16_t  kTemperatureMinValue = -4000;
static constexpr int16_t  kTemperatureMaxValue = 12500;
static constexpr uint16_t kHumidityMinValue    = 0;
static constexpr uint16_t kHumidityMaxValue    = 10000;
static constexpr float    kCO2MinPpm           = 400.0f;
static constexpr float    kCO2MaxPpm           = 5000.0f;

constexpr auto k_timeout_seconds = 600;
constexpr uint8_t kAirQualityClusterRevision = 1;

/* CO2 cluster/attributes (custom concentration measurement cluster) */
constexpr uint32_t kClusterId_CO2                = 0x040D;
constexpr uint32_t kAttrId_CO2_MeasuredValue     = 0x0000;
constexpr uint32_t kAttrId_CO2_MinMeasured       = 0x0001;
constexpr uint32_t kAttrId_CO2_MaxMeasured       = 0x0002;
constexpr uint32_t kAttrId_CO2_MeasurementUnit   = 0x0008; // 0x00=PPM
constexpr uint32_t kAttrId_CO2_MeasurementMedium = 0x0009; // 0x00=Air
constexpr uint32_t kAttrId_CO2_Uncertainty       = 0x0007; // ± measurement error (nullable float)

static uint16_t g_temp_ep_id  = 0;
static uint16_t g_humid_ep_id = 0;
static uint16_t g_co2_ep_id   = 0;
static int16_t  g_current_temp = 0;
static uint16_t g_current_humidity = 0;
static uint16_t g_current_co2 = 0;

static uint16_t g_ps_usb_ep_id    = 0;
static uint16_t g_ps_liion_ep_id  = 0;
static uint16_t g_ps_lsocl2_ep_id = 0;
static SemaphoreHandle_t s_reply_mutex = nullptr;

/* Aggregated metadata for all power sources, received from STM32 */
typedef struct {
    bool     usb_on;
    uint16_t vbat_liion_mV;
    uint16_t vbat_lsocl2_mV;
    uint8_t  charger_status; /* BQ25185_Status_t from STM, 0..6 */
} power_meta_t;

static power_meta_t g_power_meta = {};

typedef enum {
    BQ25185_STATUS_USB_NOT_CONNECTED = 0,
    BQ25185_STATUS_CHARGE_DONE,
    BQ25185_STATUS_CHARGING,
    BQ25185_STATUS_RECOVERABLE_FAULT,
    BQ25185_STATUS_FATAL_FAULT,
    BQ25185_STATUS_BATTERY_MISSING,
    BQ25185_STATUS_UNKNOWN
} BQ25185_Status_t;

static SemaphoreHandle_t g_data_mutex = nullptr;
static volatile uint32_t g_wake_count = 0;
static TaskHandle_t s_uart_task_handle = nullptr;

#if CONFIG_PM_ENABLE
static esp_pm_lock_handle_t s_pm_lock = nullptr;
#endif

static bool s_gpio_isr_installed = false;

static volatile bool s_cw_open = false;
static volatile bool s_cw_close_by_app = false;  // true when commissioning window is closed by our app logic

/* ===== Fabric/session helper: expire all sessions & subscriptions for a fabric ===== */
static void ExpireAllFabricSessionsAndSubscriptions(chip::FabricIndex fabric_index)
{
    auto & server = chip::Server::GetInstance();
    server.GetSecureSessionManager().ExpireAllSessionsForFabric(fabric_index);

#if CHIP_CONFIG_ENABLE_SESSION_RESUMPTION
    if (auto * session_resumption = server.GetSessionResumptionStorage())
    {
        (void)session_resumption->DeleteAll(fabric_index);
    }
#endif

#if CHIP_CONFIG_ENABLE_READ_CLIENT
    chip::app::InteractionModelEngine::GetInstance()->ShutdownSubscriptions(fabric_index);
    if (auto * subscription_resumption = server.GetSubscriptionResumptionStorage())
    {
        (void)subscription_resumption->DeleteAll(fabric_index);
    }
#endif
}

/* ===== PM lock helpers (NO_LIGHT_SLEEP while UART IO, commissioning, etc.) ===== */
static inline bool pm_lock_acquire_if(void)
{
#if CONFIG_PM_ENABLE
    if (s_pm_lock && esp_pm_lock_acquire(s_pm_lock) == ESP_OK) return true;
#endif
    return false;
}

static inline void pm_lock_release_if(bool held)
{
#if CONFIG_PM_ENABLE
    if (held && s_pm_lock) (void)esp_pm_lock_release(s_pm_lock);
#else
    (void)held;
#endif
}

/* ===== READY pin =====
 * Output pin driven to indicate that the ESP32 is ready to receive/process a frame.
 */
static void ready_pin_init(void)
{
    gpio_config_t io_conf = {
        .pin_bit_mask = (1ULL << kReadyPin),
        .mode = GPIO_MODE_OUTPUT,
        .pull_up_en = GPIO_PULLUP_DISABLE,
        .pull_down_en = GPIO_PULLDOWN_DISABLE,
        .intr_type = GPIO_INTR_DISABLE,
    };
    ESP_ERROR_CHECK(gpio_config(&io_conf));
    ESP_ERROR_CHECK(gpio_set_level(kReadyPin, 0));
    ESP_LOGI(TAG, "Ready pin GPIO%d configured (initial LOW)", kReadyPin);
}

static inline void ready_pin_set(bool level)
{
    gpio_set_level(kReadyPin, level ? 1 : 0);
}

/* --- WAKE read helper
 * Return current logical level of the WAKE pin, using RTC IO if available.
 */
static inline int get_wake_level(void)
{
#if SOC_RTCIO_PIN_COUNT > 0
    if (WAKE_PIN <= GPIO_NUM_7)
        return rtc_gpio_get_level((gpio_num_t)WAKE_PIN);
#endif
    return gpio_get_level(WAKE_PIN);
}

/* ===== WAKE ISR =====
 * ISR is triggered on the rising edge of WAKE. It wakes the UART task via task notification.
 */
static void IRAM_ATTR wake_gpio_isr_handler(void *arg)
{
    BaseType_t hpw = pdFALSE;
    if (s_uart_task_handle) {
        g_wake_count++;
        vTaskNotifyGiveFromISR(s_uart_task_handle, &hpw);
    }
    if (hpw == pdTRUE) {
        portYIELD_FROM_ISR();
    }
}

/* ===== UART init =====
 * Configure UART driver and wakeup behavior for low power.
 */
static void uart_init(void)
{
    const uart_config_t cfg = {
        .baud_rate = UART_BAUD_RATE,
        .data_bits = UART_DATA_8_BITS,
        .parity    = UART_PARITY_DISABLE,
        .stop_bits = UART_STOP_BITS_1,
        .flow_ctrl = UART_HW_FLOWCTRL_DISABLE,
        .source_clk= UART_SCLK_DEFAULT,
    };

    /* RX ring-buffer = 2× UART_BUF_SIZE, TX ring-buffer = 1024B (smooth UART logging) */
    ESP_ERROR_CHECK(uart_driver_install(UART_NUM, UART_BUF_SIZE * 2, 1024, 0, NULL, 0));
    ESP_ERROR_CHECK(uart_param_config(UART_NUM, &cfg));
    ESP_ERROR_CHECK(uart_set_pin(UART_NUM, UART_TX_PIN, UART_RX_PIN, UART_PIN_NO_CHANGE, UART_PIN_NO_CHANGE));
    ESP_ERROR_CHECK(gpio_pullup_en((gpio_num_t)UART_RX_PIN));
    ESP_ERROR_CHECK(uart_set_rx_full_threshold(UART_NUM, 1));
    ESP_ERROR_CHECK(uart_set_rx_timeout(UART_NUM, 4));
    ESP_ERROR_CHECK(uart_set_wakeup_threshold(UART_NUM, 3));     // minimum allowed by hardware
    ESP_ERROR_CHECK(esp_sleep_enable_uart_wakeup(UART_NUM));     // C6: UART0 and UART1 support wakeup
}

/* ===== WAKE pin init =====
 * Configure WAKE as input, with both GPIO and light-sleep wakeup, and attach ISR.
 */
static void wake_pin_init(void)
{
    gpio_config_t io_conf = {
        .pin_bit_mask = (1ULL << WAKE_PIN),
        .mode = GPIO_MODE_INPUT,
        .pull_up_en = GPIO_PULLUP_DISABLE,
        .pull_down_en = GPIO_PULLDOWN_DISABLE,
        .intr_type = GPIO_INTR_DISABLE,
    };
    ESP_ERROR_CHECK(gpio_config(&io_conf));

    ESP_ERROR_CHECK(esp_sleep_enable_gpio_wakeup());
    ESP_ERROR_CHECK(gpio_wakeup_enable(WAKE_PIN, GPIO_INTR_HIGH_LEVEL));
    ESP_ERROR_CHECK(gpio_set_intr_type(WAKE_PIN, GPIO_INTR_POSEDGE));

    if (!s_gpio_isr_installed) {
        esp_err_t err = gpio_install_isr_service(ESP_INTR_FLAG_IRAM);
        if (err == ESP_OK || err == ESP_ERR_INVALID_STATE)
            s_gpio_isr_installed = true;
        else
            ESP_LOGE(TAG, "Failed to install GPIO ISR service: %d", err);
    }

    ESP_ERROR_CHECK(gpio_isr_handler_add(WAKE_PIN, wake_gpio_isr_handler, nullptr));
    ESP_ERROR_CHECK(gpio_intr_enable(WAKE_PIN));
    ESP_LOGI(TAG, "Wake pin GPIO%d configured (ISR on rising edge, wake on HIGH)", WAKE_PIN);
}

/* Busy-wait until WAKE reaches expected_level or timeout */
static bool wait_for_wake_pin_level(int expected_level, uint32_t timeout_us)
{
    const uint32_t step_us = 50;
    uint32_t elapsed = 0;
    while (get_wake_level() != expected_level && elapsed < timeout_us) {
        esp_rom_delay_us(step_us);
        elapsed += step_us;
    }
    return get_wake_level() == expected_level;
}

/* ===== UART helpers (text I/O) ===== */
static inline void uart_write_crlf(void) {
    uart_write_bytes(UART_NUM, "\r\n", 2);
}

/* Format and send a single line over UART, appending CRLF */
static void uart_send_line_v(const char *fmt, va_list args)
{
    char buf[256];
    va_list ap;
    va_copy(ap, args);
    int n = vsnprintf(buf, sizeof(buf), fmt, ap);
    va_end(ap);
    if (n < 0) return;

    bool pm = pm_lock_acquire_if();
    uart_write_bytes(UART_NUM, buf, strnlen(buf, sizeof(buf)));
    uart_write_crlf();
    (void)uart_wait_tx_done(UART_NUM, pdMS_TO_TICKS(200)); // ensure TX completes
    pm_lock_release_if(pm);
}

/* Thread-safe printf-style helper for UART replies (uses recursive mutex) */
static void replyf(const char* fmt, ...)
{
    if (s_reply_mutex) {
        xSemaphoreTakeRecursive(s_reply_mutex, portMAX_DELAY);
    }
    va_list ap;
    va_start(ap, fmt);
    uart_send_line_v(fmt, ap);
    va_end(ap);
    if (s_reply_mutex) {
        xSemaphoreGiveRecursive(s_reply_mutex);
    }
}


/* "Block" send of a prebuilt buffer in one go over UART */
static void uart_write_block(const char* data, size_t len) {
    bool pm = pm_lock_acquire_if();
    uart_write_bytes(UART_NUM, data, len);
    (void)uart_wait_tx_done(UART_NUM, pdMS_TO_TICKS(300));
    pm_lock_release_if(pm);
}

/* Read a line from UART into 'out', stripping CR/LF, with timeout.
 * Returns number of bytes read (not including terminator).
 */
static int read_line(char* out, size_t out_sz, TickType_t timeout_ticks)
{
    size_t L = 0;
    TickType_t deadline = xTaskGetTickCount() + timeout_ticks;

    bool pm = pm_lock_acquire_if(); // keep light sleep disabled during RX window
    while (xTaskGetTickCount() < deadline && L + 1 < out_sz) {
        uint8_t c;
        int r = uart_read_bytes(UART_NUM, &c, 1, pdMS_TO_TICKS(30));
        if (r == 1) {
            if (c == '\n') break;
            if (c != '\r') out[L++] = (char)c;
        }
    }
    pm_lock_release_if(pm);

    out[L] = '\0';
    return (int)L;
}

/* ===== Battery status helpers ===== */
static inline bool battery_present_liion(uint16_t mv)
{
    return (mv >= 1000U);
}

static inline bool battery_present_lsocl2(uint16_t mv)
{
    return (mv >= 2000U);
}

/* Map raw charger state into Matter BatChargeStateEnum for the Li-Ion source */
static chip::app::Clusters::PowerSource::BatChargeStateEnum
map_charge_state_liion(uint8_t raw_status, bool usb_on)
{
    namespace PS = chip::app::Clusters::PowerSource;

    BQ25185_Status_t st = (BQ25185_Status_t)raw_status;

    if (!usb_on) {
        return PS::BatChargeStateEnum::kIsNotCharging;
    }

    switch (st) {
    case BQ25185_STATUS_CHARGING:
        return PS::BatChargeStateEnum::kIsCharging;
    case BQ25185_STATUS_CHARGE_DONE:
        return PS::BatChargeStateEnum::kIsAtFullCharge;
    case BQ25185_STATUS_USB_NOT_CONNECTED:
        return PS::BatChargeStateEnum::kIsNotCharging;
    case BQ25185_STATUS_BATTERY_MISSING:
        return PS::BatChargeStateEnum::kIsNotCharging;
    case BQ25185_STATUS_RECOVERABLE_FAULT:
    case BQ25185_STATUS_FATAL_FAULT:
        return PS::BatChargeStateEnum::kIsNotCharging;
    default:
        return PS::BatChargeStateEnum::kUnknown;
    }
}
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
extern "C" void app_main()
{
    esp_err_t err = ESP_OK;
    esp_log_level_set(TAG, ESP_LOG_INFO);
    esp_log_level_set("uart", ESP_LOG_INFO);

    ESP_LOGI(TAG, "==============================================");
    ESP_LOGI(TAG, "Matter Multi-Sensor with UART - TEXT PROTOCOL");
    ESP_LOGI(TAG, "==============================================");

    /* NVS */
    nvs_flash_init();
    InitNodeBasicInformation();
    g_data_mutex = xSemaphoreCreateMutex();
    if (s_reply_mutex == nullptr) {
        s_reply_mutex = xSemaphoreCreateRecursiveMutex();
    }

#if CONFIG_PM_ENABLE
    /* Configure PM once at boot (SED -> light sleep ON) */
    esp_pm_config_t pm_cfg = {
        .max_freq_mhz = CONFIG_ESP_DEFAULT_CPU_FREQ_MHZ,
        .min_freq_mhz = CONFIG_ESP_DEFAULT_CPU_FREQ_MHZ,
#if CONFIG_FREERTOS_USE_TICKLESS_IDLE
        .light_sleep_enable = true,
#else
        .light_sleep_enable = false,
#endif
    };
    err = esp_pm_configure(&pm_cfg);
    if (err == ESP_OK) {
        ESP_LOGI(TAG, "PM configured (light sleep %s)", pm_cfg.light_sleep_enable ? "ENABLED" : "DISABLED");
    } else {
        ESP_LOGW(TAG, "esp_pm_configure failed (%d)", err);
    }
#endif

    /* UART & GPIO BEFORE Matter */
    uart_init();
    wake_pin_init();
    ready_pin_init();

#ifdef CONFIG_ENABLE_USER_ACTIVE_MODE_TRIGGER_BUTTON
    app_driver_button_init();
#endif

    /* ===== Matter endpoints ===== */
    node::config_t node_cfg;
    node_t *node = node::create(&node_cfg, app_attribute_update_cb, app_identification_cb);
    ABORT_APP_ON_FAILURE(node != nullptr, ESP_LOGE(TAG, "Failed to create Matter node"));

    {
        /* Temperature sensor endpoint */
        temperature_sensor::config_t cfg;
        cfg.temperature_measurement.measured_value = static_cast<int16_t>(0);        // 0 = 0.00 °C (format 0.01 °C)
        cfg.temperature_measurement.min_measured_value = kTemperatureMinValue;
        cfg.temperature_measurement.max_measured_value = kTemperatureMaxValue;
        endpoint_t *ep = temperature_sensor::create(node, &cfg, ENDPOINT_FLAG_NONE, nullptr);
        ABORT_APP_ON_FAILURE(ep != nullptr, ESP_LOGE(TAG, "Failed to create temperature sensor"));
        g_temp_ep_id = esp_matter::endpoint::get_id(ep);
        ESP_LOGI(TAG, "Temperature sensor: endpoint_id=%u", g_temp_ep_id);
    }

    {
        /* Humidity sensor endpoint */
        humidity_sensor::config_t cfg;
        cfg.relative_humidity_measurement.measured_value = static_cast<uint16_t>(0); // 0 = 0.00 %
        cfg.relative_humidity_measurement.min_measured_value = kHumidityMinValue;
        cfg.relative_humidity_measurement.max_measured_value = kHumidityMaxValue;
        endpoint_t *ep = humidity_sensor::create(node, &cfg, ENDPOINT_FLAG_NONE, nullptr);
        ABORT_APP_ON_FAILURE(ep != nullptr, ESP_LOGE(TAG, "Failed to create humidity sensor"));
        g_humid_ep_id = esp_matter::endpoint::get_id(ep);
        ESP_LOGI(TAG, "Humidity sensor: endpoint_id=%u", g_humid_ep_id);
    }

    {
        /* Air Quality + CO2 (Concentration Measurement – MEA) endpoint */
        endpoint::app_base_config ep_cfg{};
        ep_cfg.identify.identify_type =
            static_cast<uint8_t>(chip::app::Clusters::Identify::IdentifyTypeEnum::kVisibleIndicator);

        endpoint_t *ep = endpoint::create(node, ENDPOINT_FLAG_NONE, nullptr);
        ABORT_APP_ON_FAILURE(ep != nullptr, ESP_LOGE(TAG, "Failed to create air quality endpoint"));
        g_co2_ep_id = esp_matter::endpoint::get_id(ep);

        ABORT_APP_ON_FAILURE(cluster::descriptor::create(ep, &(ep_cfg.descriptor), CLUSTER_FLAG_SERVER) != nullptr,
                             ESP_LOGE(TAG, "Failed to create descriptor cluster"));
        ABORT_APP_ON_FAILURE(cluster::identify::create(ep, &(ep_cfg.identify), CLUSTER_FLAG_SERVER) != nullptr,
                             ESP_LOGE(TAG, "Failed to create identify cluster"));

        esp_err_t err = endpoint::add_device_type(
            ep,
            ESP_MATTER_AIR_QUALITY_SENSOR_DEVICE_TYPE_ID,
            ESP_MATTER_AIR_QUALITY_SENSOR_DEVICE_TYPE_VERSION
        );
        ABORT_APP_ON_FAILURE(err == ESP_OK, ESP_LOGE(TAG, "Failed to tag air quality device type, err:%d", err));

        /* ---- AirQuality (0x005B) ----
           Safe choice is to keep FeatureMap = 0x0 (no extra promises) and only expose AirQuality attribute.
         */
        {
            using AQ = chip::app::Clusters::AirQuality::AirQualityEnum;

            cluster_t *aq_cl = cluster::create(ep, chip::app::Clusters::AirQuality::Id, CLUSTER_FLAG_SERVER);
            ABORT_APP_ON_FAILURE(aq_cl != nullptr, ESP_LOGE(TAG, "Failed to create AirQuality cluster"));

            cluster::global::attribute::create_feature_map(aq_cl, 0x00000000);
            cluster::global::attribute::create_cluster_revision(aq_cl, kAirQualityClusterRevision);

            attribute::create(
                aq_cl,
                chip::app::Clusters::AirQuality::Attributes::AirQuality::Id,
                ATTRIBUTE_FLAG_NONE,
                esp_matter_enum8(static_cast<uint8_t>(AQ::kUnknown))
            );
        }

        /* ---- CO2 Concentration Measurement (0x040D) ----
           Only MEA feature is used. A mandatory Uncertainty (0x0007) attribute is added.
           AVG feature is not enabled (no averaging implementation).
         */
        {
            cluster_t *co2 = cluster::create(ep, kClusterId_CO2, CLUSTER_FLAG_SERVER);
            ABORT_APP_ON_FAILURE(co2 != nullptr, ESP_LOGE(TAG, "Failed to create CO2 cluster"));

            cluster::global::attribute::create_feature_map(co2, 0x00000001); // MEA
            cluster::global::attribute::create_cluster_revision(co2, 3);

            // Mandatory for MEA (Measured/Min/Max)
            attribute::create(co2, kAttrId_CO2_MeasuredValue, ATTRIBUTE_FLAG_NONE,
                               esp_matter_nullable_float(0.0f));
            attribute::create(co2, kAttrId_CO2_MinMeasured, ATTRIBUTE_FLAG_NONE,
                               esp_matter_nullable_float(0.0f));
            attribute::create(co2, kAttrId_CO2_MaxMeasured, ATTRIBUTE_FLAG_NONE,
                               esp_matter_nullable_float(0.0f));
            attribute::create(co2, kAttrId_CO2_Uncertainty, ATTRIBUTE_FLAG_NONE,
                               esp_matter_nullable_float(0.0f));

            attribute::create(co2, kAttrId_CO2_MeasurementUnit,   ATTRIBUTE_FLAG_NONE, esp_matter_enum8(0)); // 0=PPM
            attribute::create(co2, kAttrId_CO2_MeasurementMedium, ATTRIBUTE_FLAG_NONE, esp_matter_enum8(0)); // 0=Air
        }

        ESP_LOGI(TAG, "CO2/Air Quality sensor: endpoint_id=%u", g_co2_ep_id);
    }

    /* Power Source endpoints for USB + Li-Ion + LiSOCl2 */
    init_power_source_endpoints(node);



#if CHIP_DEVICE_CONFIG_ENABLE_THREAD
    /* Set OpenThread platform config */
    esp_openthread_platform_config_t ot_cfg = {
        .radio_config = ESP_OPENTHREAD_DEFAULT_RADIO_CONFIG(),
        .host_config  = ESP_OPENTHREAD_DEFAULT_HOST_CONFIG(),
        .port_config  = ESP_OPENTHREAD_DEFAULT_PORT_CONFIG(),
    };
    set_openthread_platform_config(&ot_cfg);
#endif

    /* UART task BEFORE Matter start (so we can catch the very first WAKE after boot) */
    xTaskCreatePinnedToCore(uart_rx_task, "uart_rx", 4096, nullptr, tskIDLE_PRIORITY + 2, nullptr, 0);

    ESP_LOGI(TAG, "==============================================");
    ESP_LOGI(TAG, "System ready - waiting for STM32 data/commands");
    ESP_LOGI(TAG, "UART%d: RX=GPIO%d, TX=GPIO%d @ %d baud", UART_NUM, UART_RX_PIN, UART_TX_PIN, UART_BAUD_RATE);
    ESP_LOGI(TAG, "Wake: GPIO%d (trigger on HIGH)", WAKE_PIN);
    ESP_LOGI(TAG, "==============================================");

    /* Start Matter - LAST step */
    err = esp_matter::start(app_event_cb);
    ABORT_APP_ON_FAILURE(err == ESP_OK, ESP_LOGE(TAG, "Failed to start Matter, err:%d", err));

    ESP_LOGI(TAG, "==============================================");
    ESP_LOGI(TAG, "Matter started successfully - device is ready");
    ESP_LOGI(TAG, "==============================================");
}

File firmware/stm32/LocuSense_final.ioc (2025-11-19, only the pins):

Mcu.UserName=STM32U073RCTx
PA0.GPIO_Label=DBG_TX
PA0.Signal=USART4_TX
PA1.GPIO_Label=DGB_RX
PA1.Signal=USART4_RX
PA10.GPIO_Label=RF_RX
PA10.Signal=USART1_RX
PA2.GPIO_Label=USB_ON
PA2.Signal=GPXTI2
PA3.GPIO_Label=STAT1
PA3.Signal=GPIO_Input
PA4.GPIO_Label=STAT2
PA4.Signal=GPIO_Input
PA5.GPIO_Label=EPD_SCK
PA5.Signal=SPI1_SCK
PA6.GPIO_Label=EPD_CS
PA6.Signal=GPIO_Output
PA7.GPIO_Label=EPD_DIN
PA7.Signal=SPI1_MOSI
PA8.GPIO_Label=RF_CS
PA8.Signal=GPIO_Output
PA9.GPIO_Label=RF_TX
PA9.Signal=USART1_TX
PB0.GPIO_Label=EPD_BUSY
PB0.Signal=GPIO_Input
PB10.GPIO_Label=LED
PB10.Signal=GPIO_Output
PB11.GPIO_Label=BUTTON
PB11.Signal=GPXTI11
PB13.GPIO_Label=RF_SCK
PB13.Signal=SPI2_SCK
PB14.GPIO_Label=RF_MISO
PB14.Signal=SPI2_MISO
PB15.GPIO_Label=RF_MOSI
PB15.Signal=SPI2_MOSI
PB4.GPIO_Label=GPO
PB4.Signal=GPXTI4
PB6.GPIO_Label=SCL
PB6.Signal=I2C1_SCL
PB7.GPIO_Label=SDA
PB7.Signal=I2C1_SDA
PB8.GPIO_Label=PULL_CNTR
PB8.Signal=GPIO_Output
PC0.GPIO_Label=AN1
PC0.Signal=ADC1_IN0
PC1.GPIO_Label=AN2
PC1.Signal=ADC1_IN1
PC10.GPIO_Label=PS1
PC10.Signal=GPIO_Output
PC11.GPIO_Label=PS2
PC11.Signal=GPIO_Output
PC12.GPIO_Label=PS3
PC12.Signal=GPIO_Output
PC14-OSC32_IN.Signal=RCC_OSC32_IN
PC15-OSC32_OUT.Signal=RCC_OSC32_OUT
PC2.GPIO_Label=BAT_CTRL1
PC2.Signal=GPIO_Output
PC3.GPIO_Label=BAT_CTRL2
PC3.Signal=GPIO_Output
PC4.GPIO_Label=EPD_DC
PC4.Signal=GPIO_Output
PC5.GPIO_Label=EPD_RST
PC5.Signal=GPIO_Output
PC6.GPIO_Label=RF_GPIO1
PC6.Signal=GPIO_Output
PC7.GPIO_Label=RF_GPIO2
PC7.Signal=GPIO_Output
PC8.GPIO_Label=RF_GPIO0
PC8.Signal=GPIO_Output
PC9.GPIO_Label=RF_RST
PC9.Signal=GPIO_Output
PD2.GPIO_Label=PS4
PD2.Signal=GPIO_Output

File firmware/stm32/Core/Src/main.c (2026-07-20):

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
/* Includes ------------------------------------------------------------------*/
#include "main.h"

/* USER CODE BEGIN Includes */
#include "app.h"
#include "button_handler.h"
#include "stm32u0xx_hal.h"
/* USER CODE END Includes */

/* USER CODE BEGIN PD */
#define LSE_STARTUP_RETRY      5U
#define LSE_STARTUP_DELAY_MS   200U

/* USER CODE END PD */

ADC_HandleTypeDef hadc1;

I2C_HandleTypeDef hi2c1;

LPTIM_HandleTypeDef hlptim2;

RTC_HandleTypeDef hrtc;

SPI_HandleTypeDef hspi1;

UART_HandleTypeDef huart1;
UART_HandleTypeDef huart4;

void SystemClock_Config(void);
void MX_GPIO_Init(void);
void MX_ADC1_Init(void);
void MX_I2C1_Init(void);
void MX_RTC_Init(void);
void MX_SPI1_Init(void);
void MX_USART4_UART_Init(void);
void MX_USART1_UART_Init(void);
void MX_LPTIM2_Init(void);
/**
  * @brief  The application entry point.
  * @retval int
  */
int main(void)
{

  /* MCU Configuration--------------------------------------------------------*/

  /* Reset of all peripherals, Initializes the Flash interface and the Systick. */
  HAL_Init();

  /* Configure the system clock */
  SystemClock_Config();

  /* Initialize all configured peripherals */
  MX_GPIO_Init();
  MX_ADC1_Init();
  MX_I2C1_Init();
  MX_RTC_Init();
  MX_SPI1_Init();
  MX_USART4_UART_Init();
  MX_USART1_UART_Init();
  MX_LPTIM2_Init();
  /* USER CODE BEGIN 2 */
  HAL_RTCEx_DeactivateWakeUpTimer(&hrtc);
  ButtonHandler_Init();
  /* USER CODE END 2 */

  /* Infinite loop */
  /* USER CODE BEGIN WHILE */
  while (1)
  {
    /* USER CODE END WHILE */

    /* USER CODE BEGIN 3 */
	App_Run();
  }
  /* USER CODE END 3 */
}

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
/* USER CODE BEGIN 4 */

int _write(int file, char *ptr, int len)
{
    HAL_UART_Transmit(&huart4, (uint8_t*)ptr, len, HAL_MAX_DELAY);
    return len;
}


/* USER CODE END 4 */
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


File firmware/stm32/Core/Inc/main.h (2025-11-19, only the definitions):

#define AN1_Pin GPIO_PIN_0
#define AN1_GPIO_Port GPIOC
#define AN2_Pin GPIO_PIN_1
#define AN2_GPIO_Port GPIOC
#define BAT_CTRL1_Pin GPIO_PIN_2
#define BAT_CTRL1_GPIO_Port GPIOC
#define BAT_CTRL2_Pin GPIO_PIN_3
#define BAT_CTRL2_GPIO_Port GPIOC
#define DBG_TX_Pin GPIO_PIN_0
#define DBG_TX_GPIO_Port GPIOA
#define DGB_RX_Pin GPIO_PIN_1
#define DGB_RX_GPIO_Port GPIOA
#define USB_ON_Pin GPIO_PIN_2
#define USB_ON_GPIO_Port GPIOA
#define USB_ON_EXTI_IRQn EXTI2_3_IRQn
#define STAT1_Pin GPIO_PIN_3
#define STAT1_GPIO_Port GPIOA
#define STAT2_Pin GPIO_PIN_4
#define STAT2_GPIO_Port GPIOA
#define EPD_SCK_Pin GPIO_PIN_5
#define EPD_SCK_GPIO_Port GPIOA
#define EPD_CS_Pin GPIO_PIN_6
#define EPD_CS_GPIO_Port GPIOA
#define EPD_DIN_Pin GPIO_PIN_7
#define EPD_DIN_GPIO_Port GPIOA
#define EPD_DC_Pin GPIO_PIN_4
#define EPD_DC_GPIO_Port GPIOC
#define EPD_RST_Pin GPIO_PIN_5
#define EPD_RST_GPIO_Port GPIOC
#define EPD_BUSY_Pin GPIO_PIN_0
#define EPD_BUSY_GPIO_Port GPIOB
#define LED_Pin GPIO_PIN_10
#define LED_GPIO_Port GPIOB
#define BUTTON_Pin GPIO_PIN_11
#define BUTTON_GPIO_Port GPIOB
#define BUTTON_EXTI_IRQn EXTI4_15_IRQn
#define RF_SCK_Pin GPIO_PIN_13
#define RF_SCK_GPIO_Port GPIOB
#define RF_MISO_Pin GPIO_PIN_14
#define RF_MISO_GPIO_Port GPIOB
#define RF_MOSI_Pin GPIO_PIN_15
#define RF_MOSI_GPIO_Port GPIOB
#define RF_GPIO1_Pin GPIO_PIN_6
#define RF_GPIO1_GPIO_Port GPIOC
#define RF_GPIO2_Pin GPIO_PIN_7
#define RF_GPIO2_GPIO_Port GPIOC
#define RF_GPIO0_Pin GPIO_PIN_8
#define RF_GPIO0_GPIO_Port GPIOC
#define RF_RST_Pin GPIO_PIN_9
#define RF_RST_GPIO_Port GPIOC
#define RF_CS_Pin GPIO_PIN_8
#define RF_CS_GPIO_Port GPIOA
#define RF_TX_Pin GPIO_PIN_9
#define RF_TX_GPIO_Port GPIOA
#define RF_RX_Pin GPIO_PIN_10
#define RF_RX_GPIO_Port GPIOA
#define PS1_Pin GPIO_PIN_10
#define PS1_GPIO_Port GPIOC
#define PS2_Pin GPIO_PIN_11
#define PS2_GPIO_Port GPIOC
#define PS3_Pin GPIO_PIN_12
#define PS3_GPIO_Port GPIOC
#define PS4_Pin GPIO_PIN_2
#define PS4_GPIO_Port GPIOD
#define GPO_Pin GPIO_PIN_4
#define GPO_GPIO_Port GPIOB
#define GPO_EXTI_IRQn EXTI4_15_IRQn
#define SCL_Pin GPIO_PIN_6
#define SCL_GPIO_Port GPIOB
#define SDA_Pin GPIO_PIN_7
#define SDA_GPIO_Port GPIOB
#define PULL_CNTR_Pin GPIO_PIN_8
#define PULL_CNTR_GPIO_Port GPIOB

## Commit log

2025-11-19 clone repo
    [LocuSense_final Debug.cfg, partitions.csv]
2025-11-19 hardware files - mainborad
    [BatteryManagement.SchDoc, BuckBoost.SchDoc, EInkHeader.SchDoc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]
2025-11-28 add 3D model
    [BOT.step, TOP.step]
2025-12-15 add hardware files
    [BatteryManagement.SchDoc, BuckBoost.SchDoc, EEPROM_ID.SchDoc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]
2026-01-29 fixed E-Ink, console issue and Lora time sync.
    [WioE5.c, app.c, conf_console.c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]
2026-01-29 update HW - ESP module
    [EEPROM_ID.SchDoc, ESP32C6.SchDoc, ESP32C6_module.PcbDoc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]

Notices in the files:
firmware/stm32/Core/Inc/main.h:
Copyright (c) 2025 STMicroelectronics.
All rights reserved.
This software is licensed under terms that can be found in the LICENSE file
